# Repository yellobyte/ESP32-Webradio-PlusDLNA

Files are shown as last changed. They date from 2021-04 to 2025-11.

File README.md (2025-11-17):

# ESP32 Webradio++

This ESP32 internet radio implementation is partially based on Ed Smallenburgs (ed@smallenburg.nl) original ESP32 Radio project, version 10.06.2018. His active & very popular web radio project is documented [here](https://github.com/Edzelf/ESP32-radio).  

It all started when my much loved 1991's FM Tuner device **TECHNICS Tuner ST-G570** became obsolete and useless (at least for me). I simply couldn't listen to my favourite FM radio stations anymore after having moved abroad. Since I didn't want to part with the old longtime pal, the decision was made to give it a second life: housing a modern internet radio with lots of additional features.  

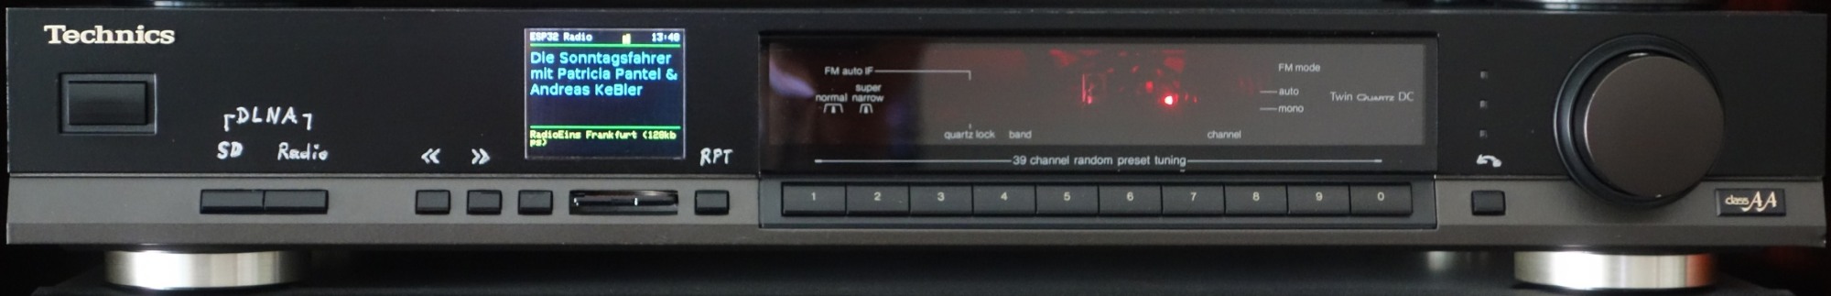
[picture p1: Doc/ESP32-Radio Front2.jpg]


Now, after putting countless hours into the project, the device not only plays **internet radio streams** and audio files from **SD cards** but also **audio content from DLNA media servers** in the same LAN.  

The Arduino library **SoapESP32** has been created especially for the latter feature and enables any ESP32 based device to connect to DLNA media servers in the local network, browse their content and download selected files. It is basically a byproduct of this project and is now listed in the official Arduino library [collection](https://www.arduino.cc/reference/en/libraries/category/communication/).  

## :gift: Feature list:

Starting from Ed Smallenburg's code (Version 10.06.2018) this project has seen a lot of additions and modifications over time. Here a summary:

 * Integration of [SoapESP32](https://github.com/yellobyte/SoapESP32) library for DLNA media server access
 * Digital audio output added (TOSLINK optical) using a WM8805 module from Aliexpress
 * Usage of special VS1053 decoder board (with I2S output and without 3.5mm audio socket)<br />
   -> You find the Eagle schematic & board files [here](https://github.com/yellobyte/ESP32-Webradio-PlusDLNA/tree/main/EagleFiles).
 * VS1053 gets patched with new firmware v2.7 at each reboot<br />
   -> Latest firmware patches for the VLSI VS1053 are available from [here](http://www.vlsi.fi/en/support/software/vs10xxpatches.html).
 * VU meter added to TFT display (needs above mentioned firmware patch)
 * Usage of W5500 Ethernet module instead of ESP32 builtin WiFi
 * Option to use a Debug Server on port 23 for debug output (in this case the cmd server is disabled due to Ethernet socket shortage)
 * Handling of the original front panel buttons & LEDs with the aid of an extender module (connected to ESP32 via I2C)
 * SD card indexing code rewritten in large parts
 * Ability to update ESP32 Radio code via SD card (using OTA functionality during reboot)
 * New rotary encoder fitted to available rotary knob, debouncing done in hardware
 * Track progress bar while playing audio files from SD card or media server
 * Minor modifications to get an unspecified Ali 21-button remote control working
 * MQTT functionality & battery stuff removed completely
 * Handling of more special chars in webradio streams (some radio channels seem to have different utf8 conversion tables)
 * Quicker handling of (very rare) firmware crashes resulting in shorter recovery/reboot time
 * Countless minor changes, adjustments, bugfixing
 * Regular modifications if required for building with new espressif32 framework releases   

If interested, have a look at [Revision history.txt](https://github.com/yellobyte/ESP32-Webradio-PlusDLNA/blob/main/Doc/Revision%20history.txt) in the doc folder. 

## Some technical details:
The original display (rendered useless) has been removed and it's plexiglass cover now hides the infrared sensor VS1838B which receives signals from a remote control. A small 1.8" TFT color display (160x128 pixel, ST7735 driver IC, PCI bus) has been added to the front and is used for interacting with the user and presenting essential info. The necessary cutout in the front has been made with a small and affordable Proxxon mill/drill unit used by many hobbyists. A thin plexiglass is glued into the cutout. The TFT display sits right behind it, mounted on a frame made from PCB material to keep it in place. 

After milling/drilling the front was thoroughly cleaned to get a smooth surface and then the upper flat part of it was painted black twice with a bottle of color spray. It rested 3 days in the sun to dry completely before being reattached to the case. A silver permanent marker was used to label the buttons later on.  

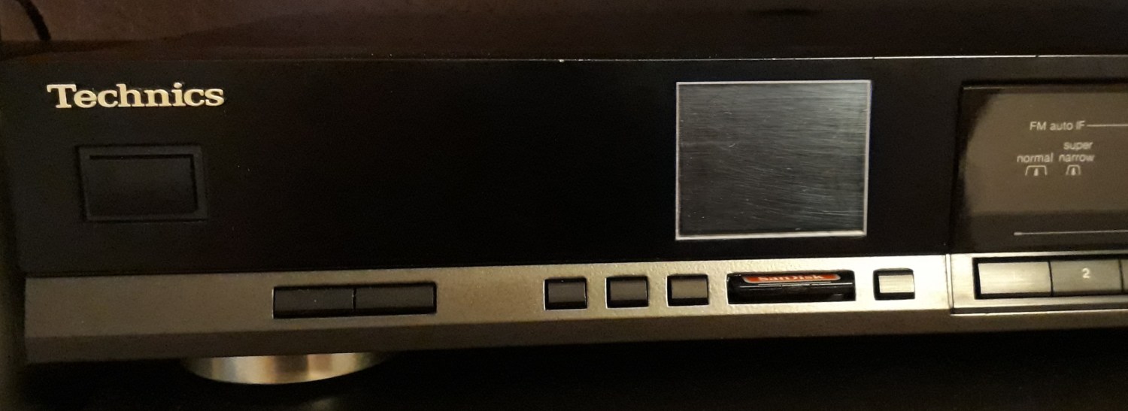
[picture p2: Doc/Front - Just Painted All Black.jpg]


The original encoder attached to the rotary knob has been replaced with a modern one (Stec Rotary Encoder STEC11B03, 1 impulse per 2 clicks, turn + push). The knob is now used to browse through the list of pre-configured web radio stations, the content of SD cards or DLNA media servers storing thousands of audio files. Going up and down the directory levels and finally selecting an audio file for playing is done very fast with the knob in combination with the small 'return' button next to it.  

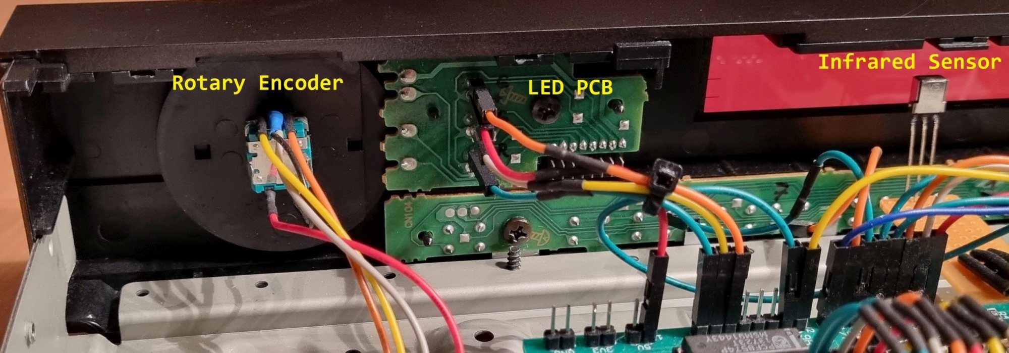
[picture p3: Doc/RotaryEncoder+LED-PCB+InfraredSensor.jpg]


Most of the original front buttons are still available and used for changing modes (Radio, SD card or DLNA), skipping tracks and selecting a repeat mode (None, Track, List or Random). Two adjacent buttons just below the TFT display went into the bin and made room for a SD card module (PCI bus with 4MHz clock speed only for stability reasons).   

A special extender board connects the mainboard with the original front PCB. This board makes it possible to control LEDs and buttons via the original control matrix. The existing 10 channel buttons (1...8,9,0) can continue to serve their original purpose, only this time with web radio stations assigned. The infrared sensor is attached to the extender board as well. 

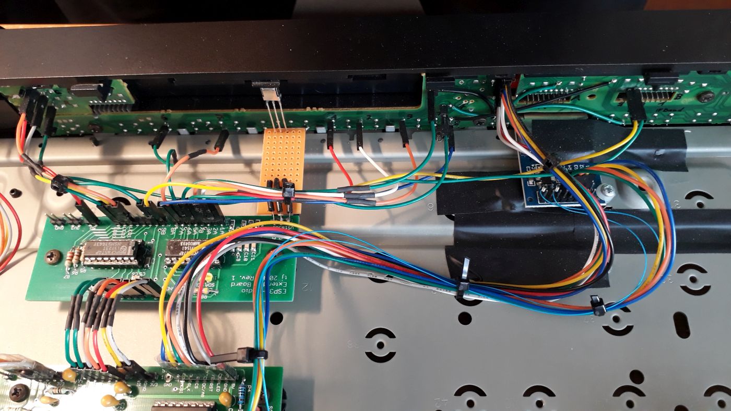
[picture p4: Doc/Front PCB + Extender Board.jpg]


The extender board contains two 'Remote 8-Bit I/O Expander for I2C Bus ICs' PCF8574 and is connected to the mainboard via I2C bus. Its only task is to provide additional IO ports to the ESP32 on the mainboard. Jumper JP1 on the board is open as the interrupt signal INT from both ICs is unused. Every ~60ms the ICs get polled from the ESP32 instead.

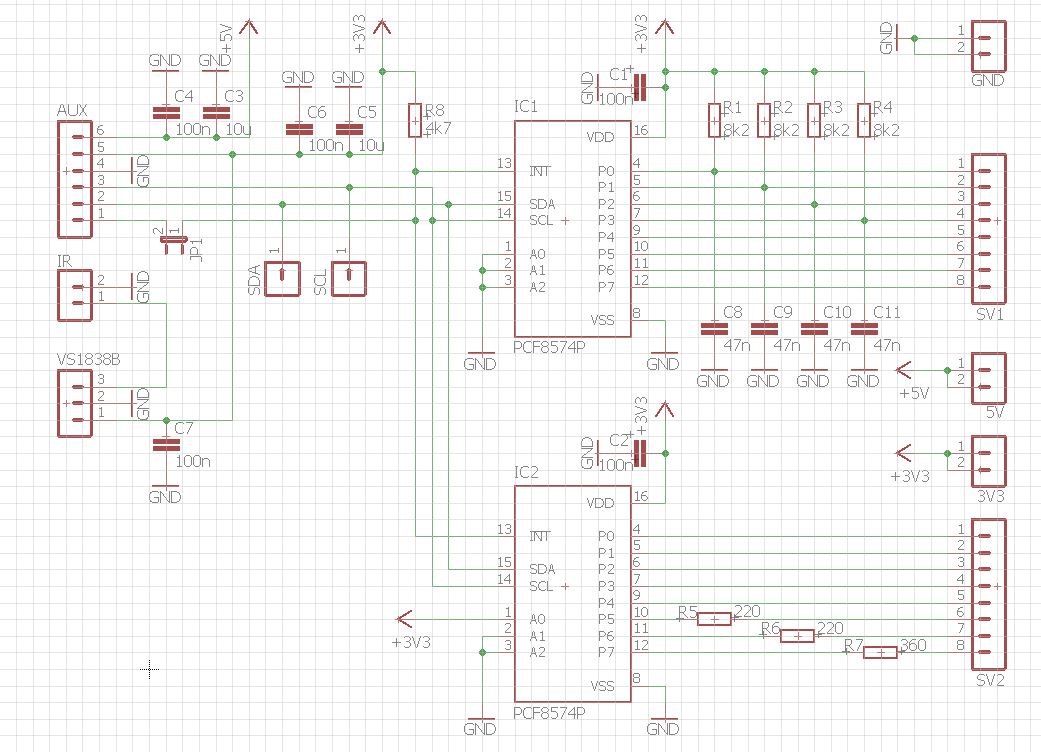
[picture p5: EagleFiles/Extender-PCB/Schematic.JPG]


The original front panel 7x4 control matrix has all buttons connected between 7 rows and 4 columns as shown below. Quite a few single header pins had to be soldered onto the front panel PCB to get electrical access to the matrix. 

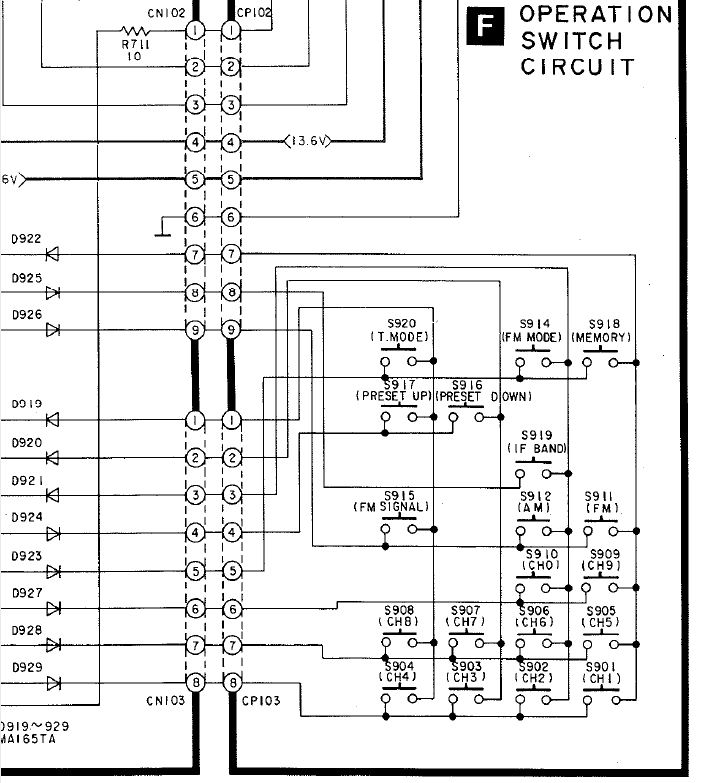
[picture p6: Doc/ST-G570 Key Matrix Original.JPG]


Rows 1...7 of the matrix (from top to bottom) are wired to connectors SV1 and SV2 on the extender board as follows:  
 * Row 1 (CP103/5) --> SV1/5 (PCF8574-1/P4, output)
 * Row 2 (CP103/4) is unused (buttons 'Preset up/down' have been removed)
 * Row 3 (CP102/8) --> SV2/2 (PCF8574-2/P1, output)
 * Row 4 (CP102/9) --> SV2/1 (PCF8574-2/P0, output)
 * Row 5 (CP103/6) --> SV1/6 (PCF8574-1/P5, output)
 * Row 6 (CP103/7) --> SV1/7 (PCF8574-1/P6, output)
 * Row 7 (CP103/8) --> SV1/8 (PCF8574-1/P7, output)

And colums 1...4 (from left to right) are wired to the extender board as follows:  
 * Column 1 (CP103/1) --> SV1/1 (PCF8574-1/P0, input, with 8.2k pull-up resistor to 3V3)
 * Column 2 (CP103/2) --> SV1/2 (PCF8574-1/P1, input, with 8.2k pull-up resistor to 3V3)
 * Column 3 (CP103/3) --> SV1/3 (PCF8574-1/P2, input, with 8.2k pull-up resistor to 3V3)
 * Column 4 (CP102/7) --> SV1/4 (PCF8574-1/P3, input, with 8.2k pull-up resistor to 3V3)

In order to detect pressed buttons the extender board successively pulls the rows LOW and checks it's column input lines for a HIGH to LOW transition because any button pressed will then subsequently pull its corresponding column to LOW as well.

The extender board additionally drives the 3 front panel LEDs via IC PCF8574-2/P5-P7 (connector pins SV2/6...8) by setting the lines to LOW. Those 3 lines plus 3V3 are wired directly to a separate LED PCB next to the rotary encoder.  

As for now, the device consists of several separate modules/PCBs. Three modules (ESP32, TOSLINK optical output, 10/100Mb Ethernet) were bought from various internet shops and the other four modules (power supply, mainboard, VS1053B decoder and front extender) were especially designed for this project with EAGLE PCB Design & Layout tool. The PCBs were ordered unassembled from various PCB prototype manufacturers in CN for little money. I did all the soldering myself, the decoder chip VS1053B in a tiny LQFP-48 package was a challenge though. All relevant EAGLE project files, schematics, board layouts etc. are available [here](https://github.com/yellobyte/ESP32-Webradio-PlusDLNA/tree/main/EagleFiles).  

The analog audio output socket, the power input socket, the common mode choke and the many PCB distance holders were harvested from the original tuner PCBs and reused. Their Eagle-Libraries are located [here](https://github.com/yellobyte/Eagle-Component-Library). The mounting holes on the new PCBs were placed in a way to match the existing mounting holes at the bottom of the case.  

A necessary audio amplifier can be connected via the analog audio output or even the TOSLINK optical output for better sound quality. Well, going digital at the output is probably useless for web radio stations only, as their stream bit rates mostly range between 32...128kbps and very rarely top 192kbps.  

The special VS1053B decoder module (the red one in the middle) provides an I2S output which connects the decoder with the TOSLINK optical output module (the green one on the left). Since all available VS1053B decoder modules on Ali etc. lacked an I2S port I unavoidably had to build my own one. 

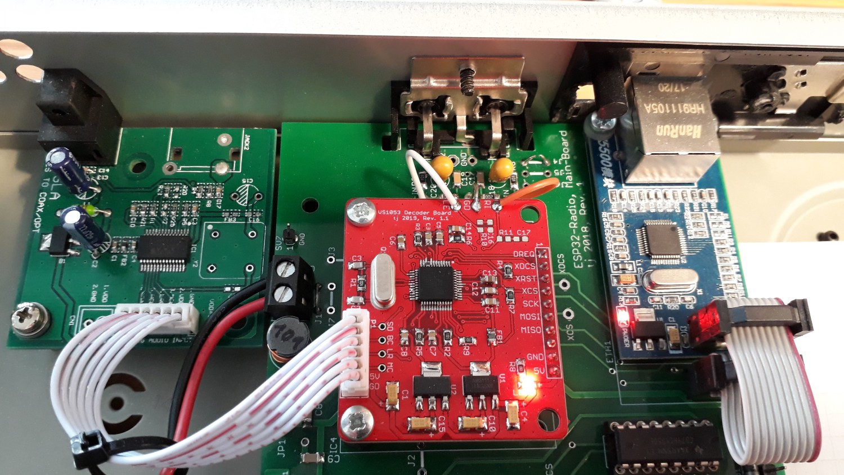
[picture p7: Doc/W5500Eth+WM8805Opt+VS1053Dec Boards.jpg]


If a digital audio output is not needed than any of the available cheap VS1053B decoder modules with 3.5mm jack socket (and without I2S socket) would do.  

The WM8805 I2S to TOSLINK module (China) was the cheapest module version I could get as it lacks the COAX output socket, the crystal oscillator, some Cs, Rs and the power input socket. However, all this is not needed in this project. Important was the ability to configure the WM8805 simply with Rs on the module and the presence of a TOSLINK output socket. 

The WM8805 can be operated in either software or hardware control mode. The mode is determined by sampling the state of the SDIN pin. If SDIN is LOW
during power up or hardware reset then the WM8805 switches into hardware control mode. In this mode most features will assume default values but some can be configured using external pins (SDOUT, SCLK, CSB, GPO0). 

Having the respective Rs soldered as shown below gives the following configuration of the chip: hardware control mode (SDIN=LOW), slave mode (SCLK=LOW), S/PDIF transmitter data source is I2S (CSB=HIGH) and the I2S interface expects 16-bit data (GPO0=LOW, SDOUT=LOW).  

To make the optical output work the decoder chip VS1053B is programmed to feed the WM8805 with 12.288MHz MCLK, 48kHz LRCK (MCLK divided by 256) and 16-bit audio data as configured.

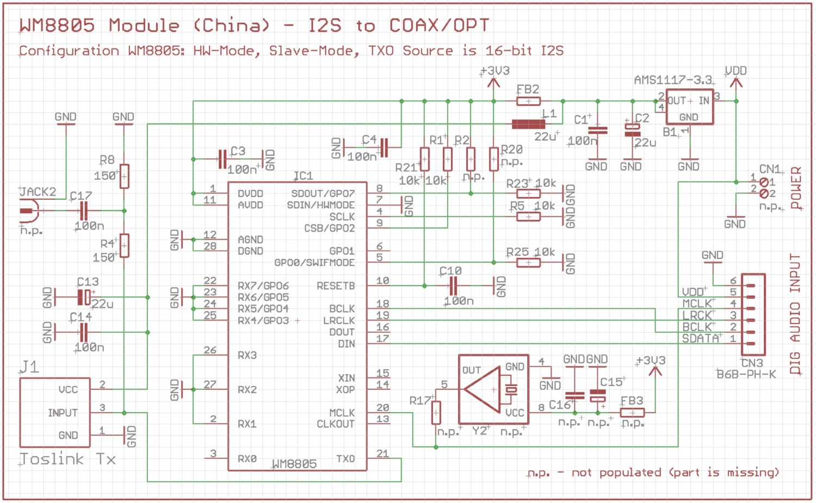
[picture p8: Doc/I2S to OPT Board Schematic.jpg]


The controller board used on the mainboard is an inexpensive ESP32-T dev board equipped with an ESP32-Bit module (4MB Flash, 512kB RAM, no PSRAM, ultra small SMD WLAN antenna, I-PEX WLAN socket). Compared with other popular ESP32 dev boards the ESP32-T is slimmer and therefore even more breadboard compatible. I used it in the first flying test set and since it worked without issues I decided to keep it in the final project.

For my next similar project (this time an old Denon TU-550 tuner case from the early 90's) I will use the [YB-ESP32-S3-ETH dev board](https://github.com/yellobyte/YB-ESP32-S3-ETH) as it combines ESP32 + Ethernet + Wifi + debug port on a single small dev board. Both versions -N4 and -N8R8 will do but the latter provides 8MB PSRAM which allows buffering audio streams if that was needed. This board will allow to make the main board much smaller as well.

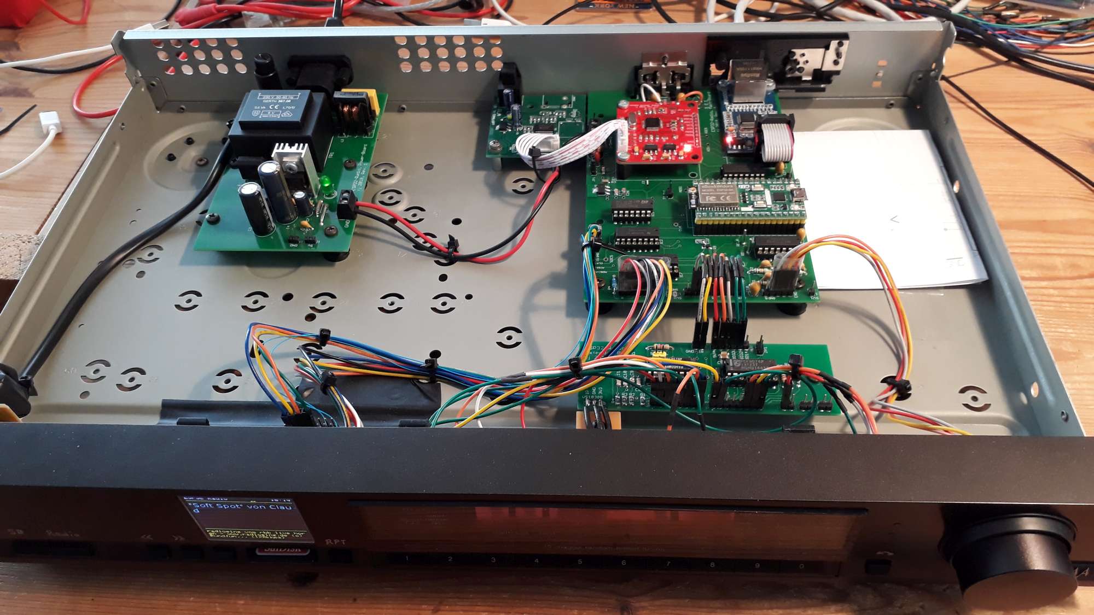
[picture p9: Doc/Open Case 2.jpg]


During the early stages of the project a lot of software updates were required and all were done via USB cable between ESP32-module and PC. However, at some stage the device rejoined the HiFi rack and opening the case now and then for a quick software update became a real pain in the butt. Hence the possibility to perform an ESP32 firmware update simply via SD card was added.  

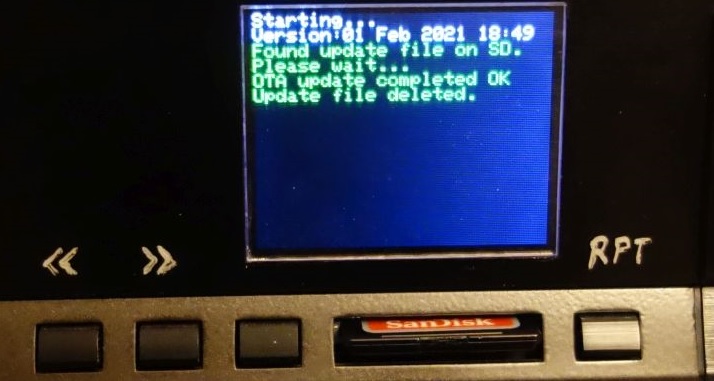
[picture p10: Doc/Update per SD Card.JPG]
  

Plenty of holes were drilled at the back of the case for better thermal management but they later proved unnecessary as the temps inside the case always stayed below 35 degs even with the lid on and all holes covered.  

If Ethernet is not wanted/possible than a small WLAN antenna attached with a short cable to the ESP32 WLAN-socket (I-PEX) would suffice. In that case I recommend to place the antenna directly behind the plexiglass cover for better receiption. Early tests with a WLAN router in 3m distance and fully closed case showed no issues with that arrangement.  

## Hardware troubleshooting:

In the early stages of the project the device was sometimes not able to establish an Ethernet connection after being switched on and it took me quite a while to figure out the problem. As it turned out, the W5500 Ethernet chip needs to be resetted substantially longer after power on than e.g the ESP32 chip.  Hence I modified the mainboard and replaced the original RC combination holding the reset line low with a Microchip MCP130T-315. This is a voltage supervisory IC designed to keep a microcontroller or any other chip in reset for a determined time (typically 350ms) after the system voltage has reached the desired level (here >= 3.15V) and stabilized. With that chip the connection issue vanished for good. 

Another troubling issue were the infrequent system resets after inserting a SD card into the SD card socket while the system was running. I figured it might be the MISO signal from the SD card module being directly attached to the ESP32. After adding driver gates IC2B (HC4050) and IC3D (74HC125) into the path between ESP32 and SD module this problem was gone as well. This solution disconnects the SD modules's MISO signal from the system and therefor prevents any interference from the SD card module when its assigned chip select signal SDCS is inactive (high). 

Since mechanical rotary encoders (independent of their build quality) need to be debounced I decided very early in the project to perform it fully in hardware by using RC circuits (10k/100n) in combination with Schmitt-Trigger ICs (74HC14).  As expected, debouncing issues never surfaced and no line of code had to be wasted on this topic.  

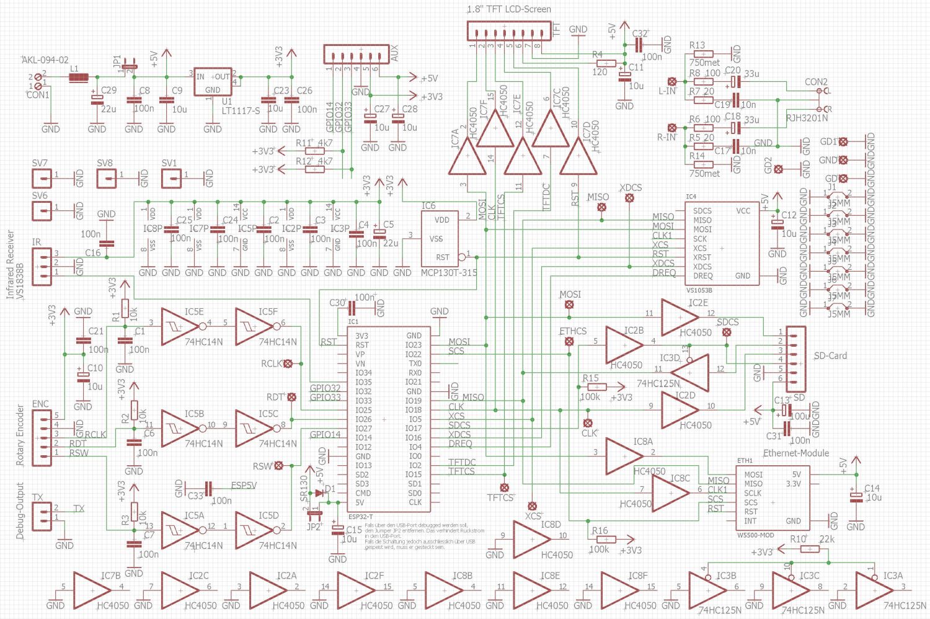
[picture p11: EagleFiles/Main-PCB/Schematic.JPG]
  

As visible in the main board schematic above, the inputs of all unused 74HC gates are kept grounded and not floating in order to avoid possible gate oscillation as their inputs are all high impedance (in contrast to e.g. old 7400's). Furthermore I added plenty of capacitors near the ICs and close to each socket, connector etc. in order to keep the power supply rail as clean as possible.

## :zap: Software application notes:

All coding was done with **VSCode/PlatformIO-IDE**. To install needed libraries (Ethernet, SoapESP32, etc.) click the **PlatformIO sidebar icon**, open the **libraries** view and search for libs. Once found, select the newest release and click on **Add to Project**.

Always make sure you have one of the latest versions of **Arduino espressif32 framework** installed. Older versions might produce build errors. Building the project was successfully done with latest espressif32 frameworks V4.2.0, V5.0.0 and V6.0.0. Have a look at file [platformio.ini](https://github.com/yellobyte/ESP32-Webradio-PlusDLNA/blob/main/Software/platformio.ini) for required settings.

**Important:**  
Building with the official Arduino Ethernet library **and** with build options `ENABLE_CMDSERVER` or `PORT23_ACTIVE` will produce a build error like this:  
```
src\main.cpp:394:19: error: cannot declare variable 'cmdserver' to be of abstract type 'EthernetServer'
 EthernetServer    cmdserver(80);                         // Instance of embedded webserver, port 80
In file included from C:\users\tj\.platformio\packages\framework-arduinoespressif32\cores\esp32/Arduino.h:152:0,
                 from src\main.cpp:108:
C:\users\tj\.platformio\packages\framework-arduinoespressif32\cores\esp32/Server.h:28:18: note:         virtual void Server::begin(uint16_t)
     virtual void begin(uint16_t port=0) =0;
```
In this case file *Ethernet.h* in the Ethernet lib needs to be modified. Just change line  
```
class EthernetServer : public Server {
```
to
```
class EthernetServer : public Print {
```

## :tada: Implementation of SoapESP32 library for DLNA server access

The lib makes retrieving audio files from a DLNA media server a breeze: Function *browseServer()* is used to scan the server content and return a list of tracks (audio files). The device then selects an item from the list and sends a read request to the media server using *readStart()*. If granted, it will repeatedly *read()* a chunk of data into the queue which feeds the audio codec VS1053B until end of file. Finally the data connection to the server is closed with *readStop()* and the next item from the list is requested, provided the 'repeat file/folder' mode is active.  

The following sample picture sequence shows the actual implementation into this webradio project:

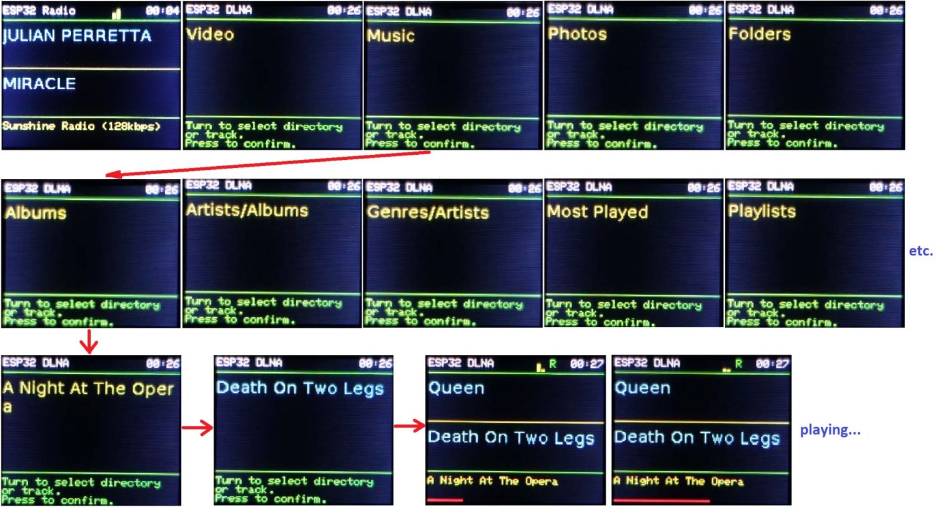
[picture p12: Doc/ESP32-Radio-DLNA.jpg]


Alternatively have a look at the short clip _ESP32-Radio-DLNA.mp4_ in folder **Doc** to see the final implementation in action. To watch now, click [Here](https://github.com/yellobyte/ESP32-Webradio-PlusDLNA/blob/main/Doc/ESP32-Radio-DLNA.mp4).

## :hammer_and_wrench: Still to be done:

 * Enable the Webinterface to browse DLNA media servers and select audio files for playing.

## :relaxed: Postscript:

Maybe this project can inspire one or two owners of old HiFi equipment to give their devices a second chance instead of tossing them into the scrap metal container. I spent a lot of time and efforts doing this project and wouldn't want to miss a second of it for I had plenty of fun and learned many things as well.  

If you have questions, miss some information or have suggestions, feel free to create an issue or contact me. However, my response time might be slow at times.

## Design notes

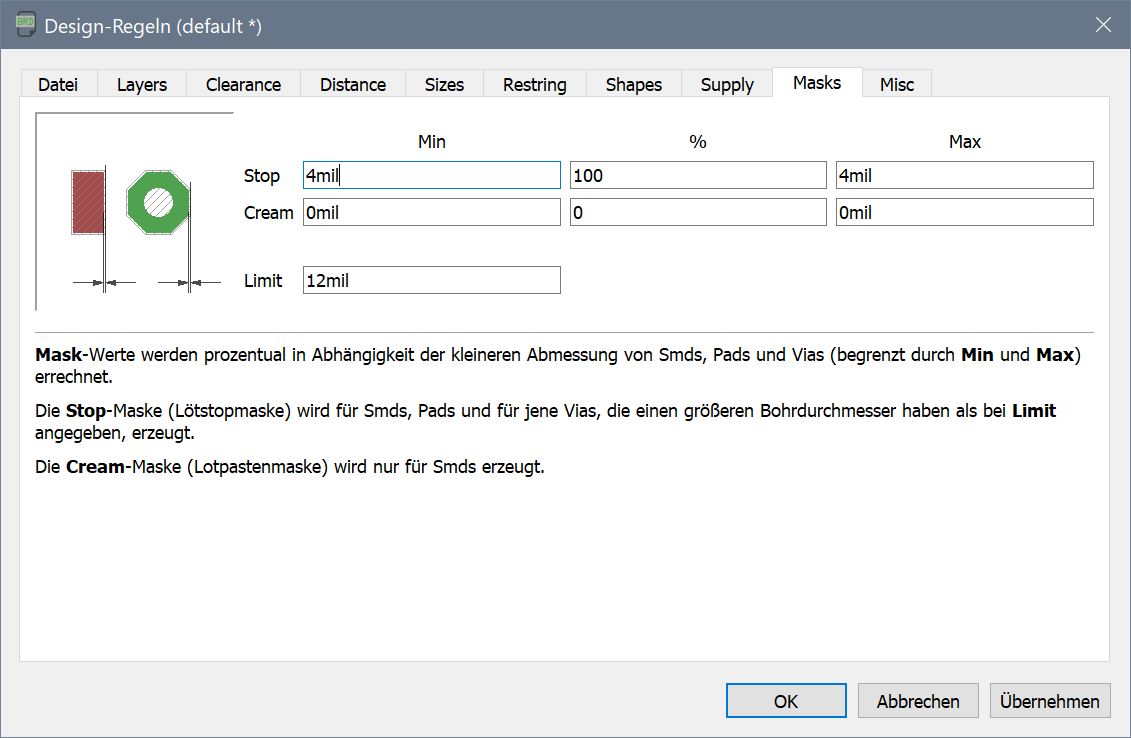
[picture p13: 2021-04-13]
EagleFiles/VS1053-PCB/Design-Masks.JPG

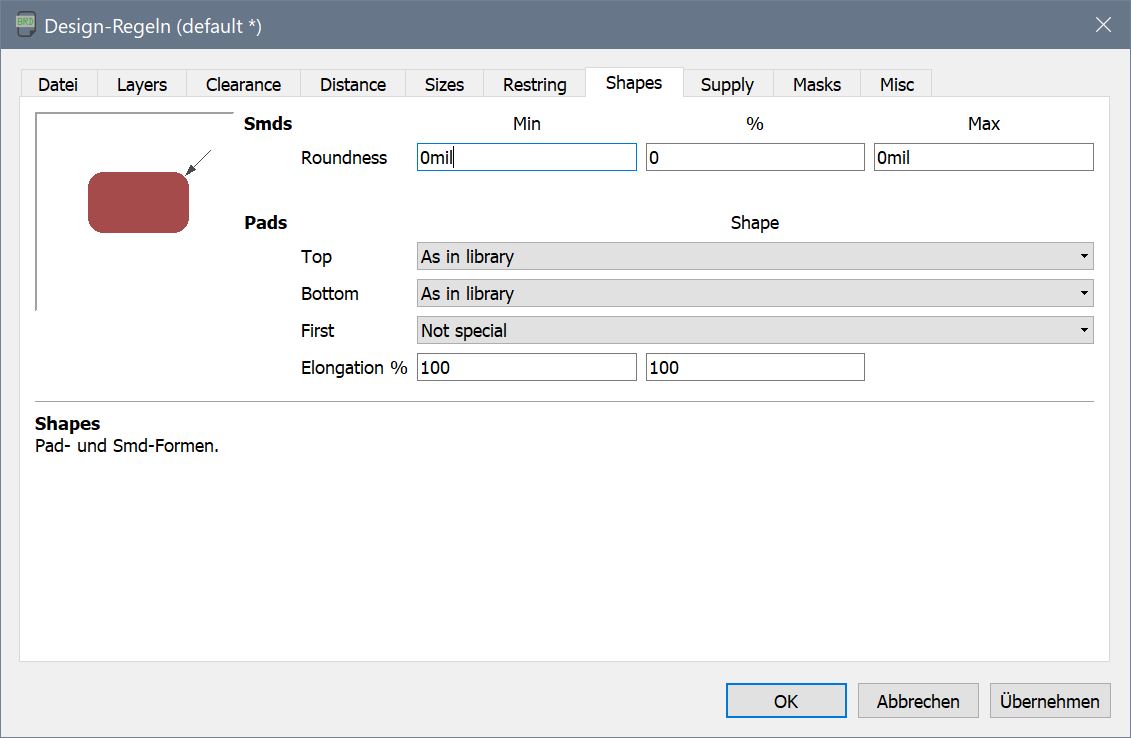
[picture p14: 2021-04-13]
EagleFiles/VS1053-PCB/Design-Shapes.JPG

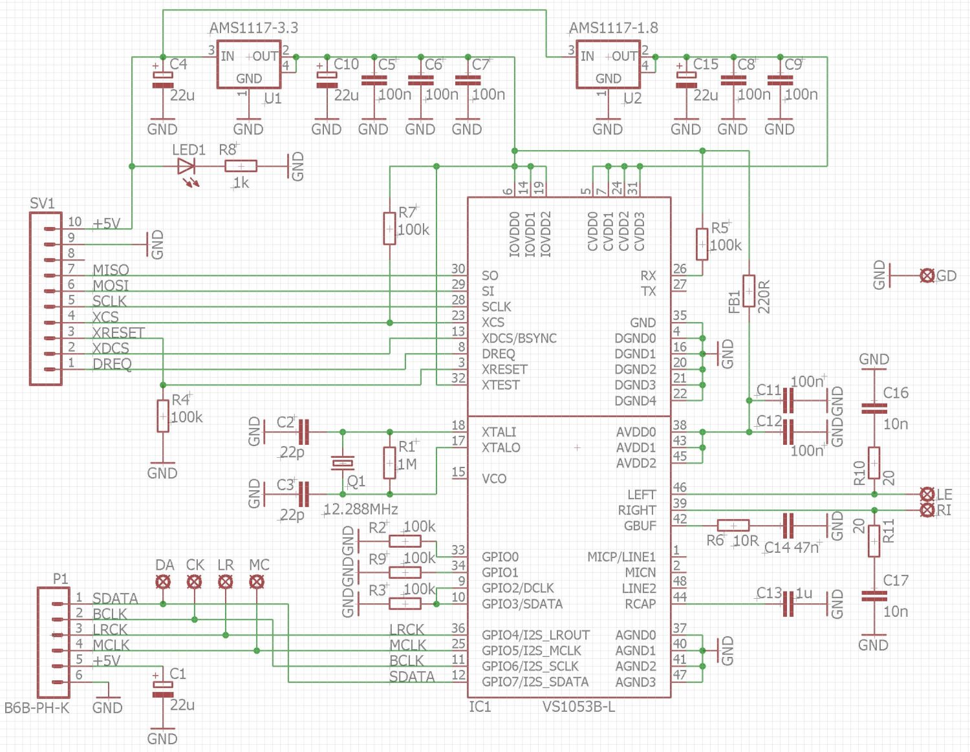
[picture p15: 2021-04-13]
EagleFiles/VS1053-PCB/Schematic.JPG

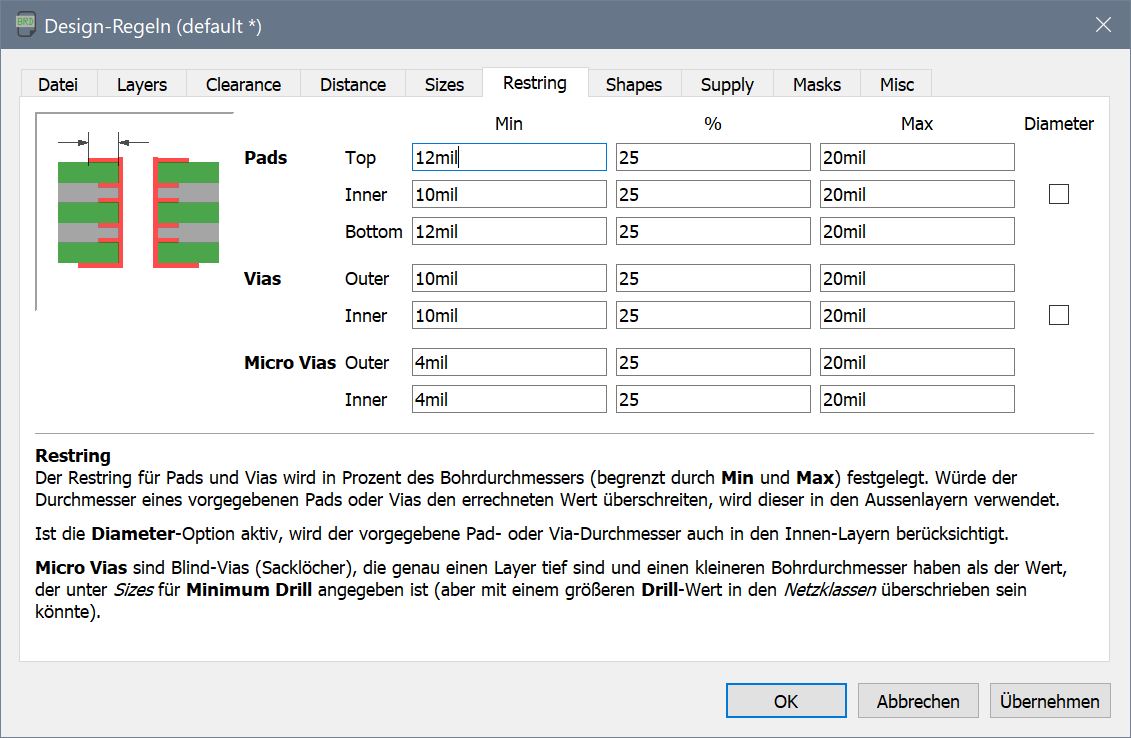
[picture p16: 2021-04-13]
EagleFiles/Main-PCB/Design-Restring.JPG

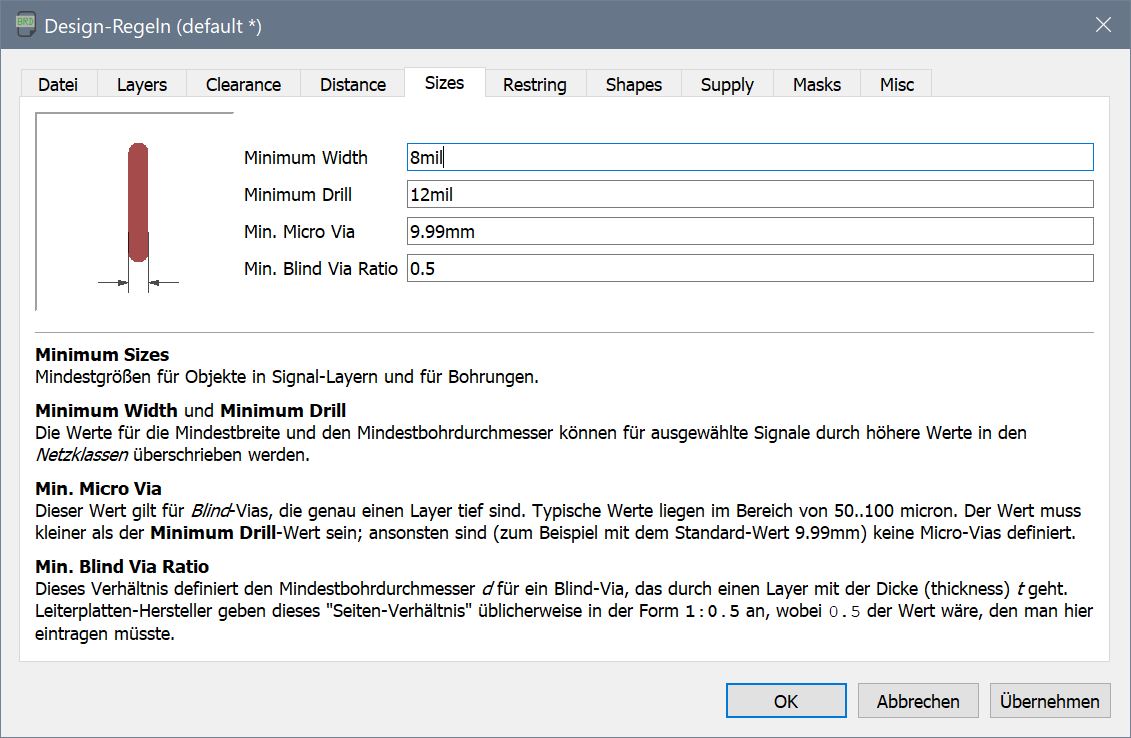
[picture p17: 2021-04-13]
EagleFiles/VS1053-PCB/Design-Sizes.JPG

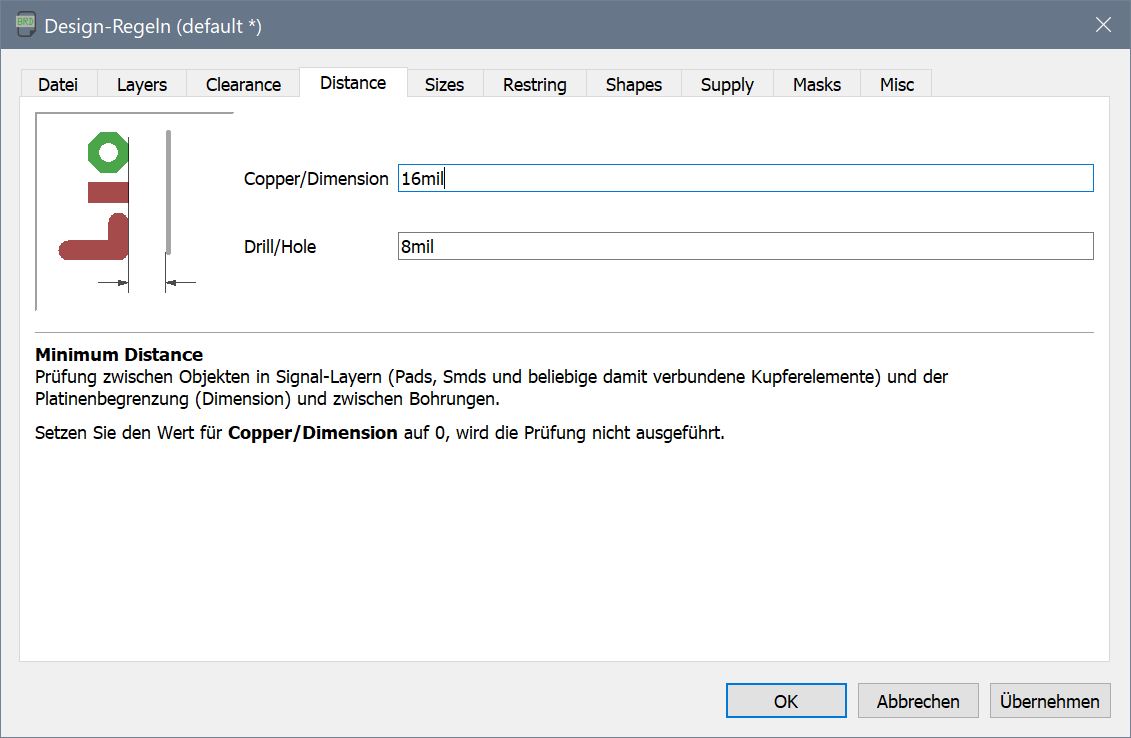
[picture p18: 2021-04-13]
EagleFiles/Main-PCB/Design-Distance.JPG

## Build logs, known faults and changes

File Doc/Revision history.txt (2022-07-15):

26-04-2017, ES: First set-up, derived from ESP8266 version.
08-05-2017, ES: Handling of preferences.
22-05-2017, ES: Save preset, volume and tone settings.
23-05-2017, ES: No more calls of non-iram functions on interrupts.
24-05-2017, ES: Support for featherboard.
26-05-2017, ES: Correction playing from .m3u playlist. Allow single hidden SSID.
30-05-2017, ES: Add SD card support (FAT format), volume indicator.
26-06-2017, ES: Correction: start in AP-mode if no WiFi networks configured.
28-06-2017, ES: Added IR interface.
30-06-2017, ES: Improved functions for SD card play.
03-07-2017, ES: Webinterface control page shows current settings.
08-07-2017, ES: More space for streamtitle on TFT.
18-07-2017, ES: Time Of Day on TFT.
19-07-2017, ES: Minor corrections.
26-07-2017, ES: Flexible pin assignment. Add rotary encoder switch.
27-07-2017, ES: Removed tinyXML library.
18-08-2017, Es: Minor corrections
28-08-2017, ES: Preferences for pins used for SPI bus,
                Corrected bug in handling programmable pins,
                Introduced touch pins.
30-08-2017, ES: Added MDNS responder.
11-11-2017, ES: Increased ringbuffer.  Measure bit rate.
13-11-2017, ES: Forward declarations.
16-11-2017, ES: Replaced ringbuffer by FreeRTOS queue, play function on second CPU,
                Included improved rotary switch routines supplied by fenyvesi,
                Better IR sensitivity.
30-11-2017, ES: Hide passwords in config page.
01-12-2017, ES: Better handling of playlist.
07-12-2017, ES: Faster handling of config screen.
08-12-2017, ES: Added pin_shutdown.
13-12-2017, ES: Correction clear LCD.
15-12-2017, ES: Correction defaultprefs.h.
18-12-2017, ES: Stop playing during config.
02-01-2018, ES: Stop/resume is same command.
22-01-2018, ES: Read ADC (GPIO36) and display as a battery capacity percentage.
13-02-2018, ES: Stop timer during NVS write.
15-02-2018, ES: Correction writing wifi credentials in NVS.
03-03-2018, ES: Correction bug IR pinnumber.
05-03-2018, ES: Improved rotary encoder interface.
10-03-2018, ES: Minor corrections.
13-04-2018, ES: Guard against empty string send to TFT, thanks to Andreas Spiess.
16-04-2018, ES: ID3 tags handling while playing from SD.
25-04-2018, ES: Choice of several display boards.
30-04-2018, ES: Bugfix: crash when no IR is configured, no display without VS1063.
08-05-2018, ES: 1602 LCD display support (limited).
11-05-2018, ES: Bugfix: incidental crash in isr_enc_turn().
30-05-2018, ES: Bugfix: Assigned DRAM to global variables used in timer ISR.
31-05-2018, ES: Bugfix: Crashed if I2C is used, but pins not defined.
01-06-2018, ES: Run playTask on CPU 0.
04-06-2018, ES: Made handling of playlistdata more tolerant (NDR).
09-06-2018, ES: Typo in defaultprefs.h
10-06-2018, ES: Rotary encoder, interrupts on all 3 signals.
21-06-2018, TJ: Bugfix in ID3-Tag recognition, new: utf16ascii()
22-06-2018, TJ: reconnect to same station as first try if station is lost
25-06-2018, TJ: unused MQTT & battery parts removed
27-06-2018, TJ: Bugfix in getSDfilename(), repeat-Mode added
01-07-2018, TJ: Showing directory names on tracklist in web interface
02-07-2018, TJ: Fast Forward for mp3 files added + misc bug fixes + changes for encoder handling
07-07-2018, TJ: Bugfixing showStreamTitle(), Changes for TFT Output with different Fonts etc.
12-07-2018, TJ: Changes in TFT Layout, progress bar, more bug fixing
15-07-2018, TJ: Ethernet added (per #define changeable between WiFi or Ethernet)
16-07-2018, TJ: DHCP or static IP addresses configurable via preferences. If rotary button is pressed
                while rebooting than DHCP will be tried first
17-07-2018, TJ: NTP server access when Ethernet/LAN is used, getLocalTimeEth()
22-07-2018, TJ: Completely new design for file listing & indexing
06-08-2018, TJ: Bugfixing in various functions, changes in mp3loop
25-08-2018, TJ: Completely different Encoder handling (spikes are now suppressed by hardware)
27-08-2018, TJ: Connecting to Port Extender ICs PCF8574 via I2C
28-08-2018, TJ: Handling of original TECHNICS ST-G570 front panel buttons & LEDs
06-09-2018, TJ: ESP32-I2C system doesn't work stable. We generate our own I2C code. Quick & dirty.
07-09-2018, TJ: Changing front panel behaviour heavily
26-09-2018, TJ: Bug fixing, changings in defaultprefs.h
08-10-2018, TJ: Changes for displaying Radio stations
16-10-2018, TJ: I2C software changed (we use low level I2C functions now, i2c_xxx [provided by espressif])
30-11-2018, TJ: In case no station name gets send we use preset name (if it exists)
01-12-2018, TJ: Show selected station names instantaneously when skip/preset buttons pressed
02-12-2018, TJ: getTime() & mp3loop() optimized, defaultprefs.h modified
03-12-2018, TJ: playing iRadio stations optimized, bugfixing
29-01-2019, TJ: MP3 progress bar with finer granularity
09-02-2019, TJ: Debug Output on Port 23 added (if PORT23_ACTIVE defined)
11-02-2019, TJ: We use standard Arduino Ethernet Library V2.0.0 instead of Wiznet Library
06-03-2019, TJ: SD_MAXDEPTH increased, Error message improved for swapped SD cards, 
                System Volume Directories suppressed in SD track list
15-05-2019, TJ: Re-Init W5500 ethernet card if connection to server is lost
16-05-2019, TJ: Removed mp3client.flush() from stopMp3client(): it hangs quite often !
08-09-2019, TJ: Show more chars in bottom segment when in radio mode (incl. conversion of spec. chars)
12-09-2019, TJ: quickSdCheck() for better handling of removed/re-inserted SD-cards
20-09-2019, TJ: File selection process from SD card slightly changed
08-10-2019, TJ: SD-Card is not scanned after switching on, only if user presses SD button.
                This speeds up the boot process.
11-10-2019, TJ: I2S Interface turned on (for new VS1053B decoder board & optical digital output),
                VS1053B patch V2.7 is loaded into VS1053B chip at every system boot and Bits 8 & 0 in
                register SCI_STATUS are set, this activates a higher reference voltage
19-10-2019, TJ: The VS1053 patch introduces a VU-Meter function. We use it in the new task "vumeterTask". 
18-04-2020, TJ: Switching from SD- to Station-Mode selects the actual station preset and not the first station
19-04-2020, TJ: Introduced Update via SD-Card (File "firmware.bin" must be in root directory)
28-11-2020, TJ: Update for VU-Meter, adjust VU meter for changing levels: radio/sdcard produce different output levels & dynamic
01-12-2020, TJ: utf8ascii modified
02-01-2020, TJ: integration of SoapESP32 for playing files from DLNA media server
09-04-2022, TJ: mp3play_html.h modified (ensure refresh of mp3 list)
10-05-2022, TJ: Faster recovery after loss of station (timer10sec() -> timer5sec())
14-07-2022, TJ: Required modifications for espressif32 frameworks >= V4.2.0
15-07-2020, TJ: utf8ascii(), displayinfo() and limitString() improved

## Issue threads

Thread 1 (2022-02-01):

Build errors

artiezz, 2022-02-01:
Using VS/PlatformIO.
First attempt: Ethernet.h: No such file or directory. Followed suggested link and added lib_deps = arduino-libraries/Ethernet@^2.0.0 to platformio.ini.
Second attempt: SoapESP32.h: No such file or directory. I gave up.
Have you built this code from a clean load?

yellobyte, 2022-02-02:
In VSCode/PlatformIO click the platformio sidebar icon, open the libraries view and search for Ethernet & SoapESP32. Once found, always select the newest release and click on **Add to Project**.
Try this in platformio.ini:
```
lib_deps = Wire, Adafruit BusIO, SoapESP32, Ethernet
lib_ldf_mode = chain+
```

Build log should look similar like this:
```c
Scanning dependencies...
Dependency Graph
|-- <Wire> 1.0.1
|-- <Adafruit BusIO> 1.10.3
|   |-- <Wire> 1.0.1
|   |-- <SPI> 1.0
|-- <SoapESP32> 1.1.1
|   |-- <Ethernet> 2.0.0
|   |   |-- <SPI> 1.0
|-- <FS> 1.0
|-- <SD(esp32)> 1.0.5
|   |-- <FS> 1.0
|   |-- <SPI> 1.0
|-- <SPI> 1.0
|-- <Update> 1.0
|-- <WiFi> 1.0
|-- <Ethernet> 2.0.0
|   |-- <SPI> 1.0
|-- <Adafruit ST7735 and ST7789 Library> 1.8.2
|   |-- <Adafruit GFX Library> 1.10.13
|   |   |-- <SPI> 1.0
|   |   |-- <Adafruit BusIO> 1.10.3
|   |   |   |-- <Wire> 1.0.1
|   |   |   |-- <SPI> 1.0
|   |   |-- <Wire> 1.0.1
|   |-- <SPI> 1.0
|-- <Adafruit GFX Library> 1.10.13
|   |-- <SPI> 1.0
|   |-- <Adafruit BusIO> 1.10.3
|   |   |-- <Wire> 1.0.1
|   |   |-- <SPI> 1.0
|   |-- <Wire> 1.0.1
Building in release mode
Compiling .pio\build\esp32dev\libc42\Adafruit BusIO\Adafruit_BusIO_Register.cpp.o
........
Archiving .pio\build\esp32dev\lib2c1\libAdafruit ST7735 and ST7789 Library.a
Archiving .pio\build\esp32dev\lib278\libAdafruit GFX Library.a
Archiving .pio\build\esp32dev\libc42\libAdafruit BusIO.a
Linking .pio\build\esp32dev\firmware.elf
Retrieving maximum program size .pio\build\esp32dev\firmware.elf
Checking size .pio\build\esp32dev\firmware.elf
Advanced Memory Usage is available via "PlatformIO Home > Project Inspect"
RAM:   [==        ]  17.9% (used 58764 bytes from 327680 bytes)
Flash: [=====     ]  51.7% (used 1016326 bytes from 1966080 bytes)
```
Show me your build log in case you need further help. Tx Th

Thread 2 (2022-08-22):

VS1053 initialisation error

DSangyy, 2022-08-22:
Awsome project you have, i am using it for my mini music client.
I've stumbled upon a problem, ENABLE_DIGITAL_INPUTS must be enabled for VS1053 to work, else it will raise "VS1053 not properly installed". I use pin 27, 14, 26 for cs, dcs, dreq. Guess the problem is pin 26 could not be read properly.

yellobyte, 2022-08-22:
Hi there, thanks for your reply. I appreciate that.
Having a look at the code I see in function readIOprefs() the value for dreq_pin is assigned a default value (in my case: 4) unless you specify otherwise in the config file via Webbrowser.
Then in setup() the VS1053 object is created and initialized with above chosen DREQ pin number:
...
  vs1053player = new VS1053(ini_block.vs_cs_pin,        // Make instance of player
                            ini_block.vs_dcs_pin,
                            **ini_block.vs_dreq_pin,**      <------------- DREQ pin number
                            ini_block.vs_shutdown_pin);
...
A few lines further down is a function call to the VS1053 initialization routine:
...
  **vs1053player->begin();**                               // initialize VS1053 player
...
In this initialization routine the actual ESP32 port (DREQ should be connected to) gets initialized:
...
void VS1053::begin()
{
  **pinMode(dreq_pin, INPUT);**                            // DREQ is an input         <------------- DREQ pin initialized
  pinMode(cs_pin, OUTPUT);                             // the SCI and SDI signals
...
So without ENABLE_DIGITAL_INPUTS being defined the ESP32 DREQ port gets initialized properly in any case. Furthermore after an ESP32 reset all ports are set by default to mode INPUT anyway.
From my point of view defining ENABLE_DIGITAL_INPUTS is not necessary for the VS1053 to work. My project runs ok this way.

You can try modifying above line to  "pinMode(dreq_pin, **INPUT_PULLUP**);" and see if it changes anything. That might suppress the error in case the VS1053 DREQ line is not properly connected to the ESP32 and you don't have a **pullup resistor** on that pin. However, without that connection it won't work later on.
I hope I have understood your problem accurately, otherwise come back to me.
Regards Thomas

yellobyte, 2022-08-24:
An oscilloscope helped me a lot finding errors, wouldn't want to live without one. Let me know how it goes. Good luck.
BTW: If you like this project, please give it a star. Thanks. :-)

Closed 2023-03-18.

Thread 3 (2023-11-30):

How to make simple DLNA audio player?

skylai82, 2023-11-30:
Is this posible using ESp32-s2 to make it DLNA audio player?

yellobyte, 2023-12-02:
The project builds without errors for ESP32/ESP32-S2/ESP32-S3.

skylai82, 2023-12-02:
> The project builds without errors for ESP32/ESP32-S2/ESP32-S3.

Can you share a simple DLNA code?  ：） I want stream my phone Music player to DLNA  ESP32 speaker.

yellobyte, 2023-12-02:
Sorry, I don't get what you want exactly....

skylai82, 2023-12-02:
> Sorry, I don't get what you want exactly....
Make my ESP32-S2 + MAX98357A like product below.
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

skylai82, 2023-12-02:
> You want to receive audio from a dlna server with ESP32, send it to a MAX98357A and play it via loudspeaker ?

Yes, it this possible? :)

yellobyte, 2023-12-02:
yes

yellobyte, 2023-12-04:
It is online: https://github.com/yellobyte/ESP32-Webradio-PlusDLNA/tree/main/Software/src  Feel free to take it as a starting point.

skylai82, 2023-12-04:
> It is online: https://github.com/yellobyte/ESP32-Webradio-PlusDLNA/tree/main/Software/src Feel free to take it as a starting point.

Thanks！ I will try to simplify code to my Internet Radio.
I've seen it before, but it's quite complicated for a beginner like me. ：）
Good Night.

yellobyte, 2023-12-04:
Have fun !

Closed 2023-12-29.

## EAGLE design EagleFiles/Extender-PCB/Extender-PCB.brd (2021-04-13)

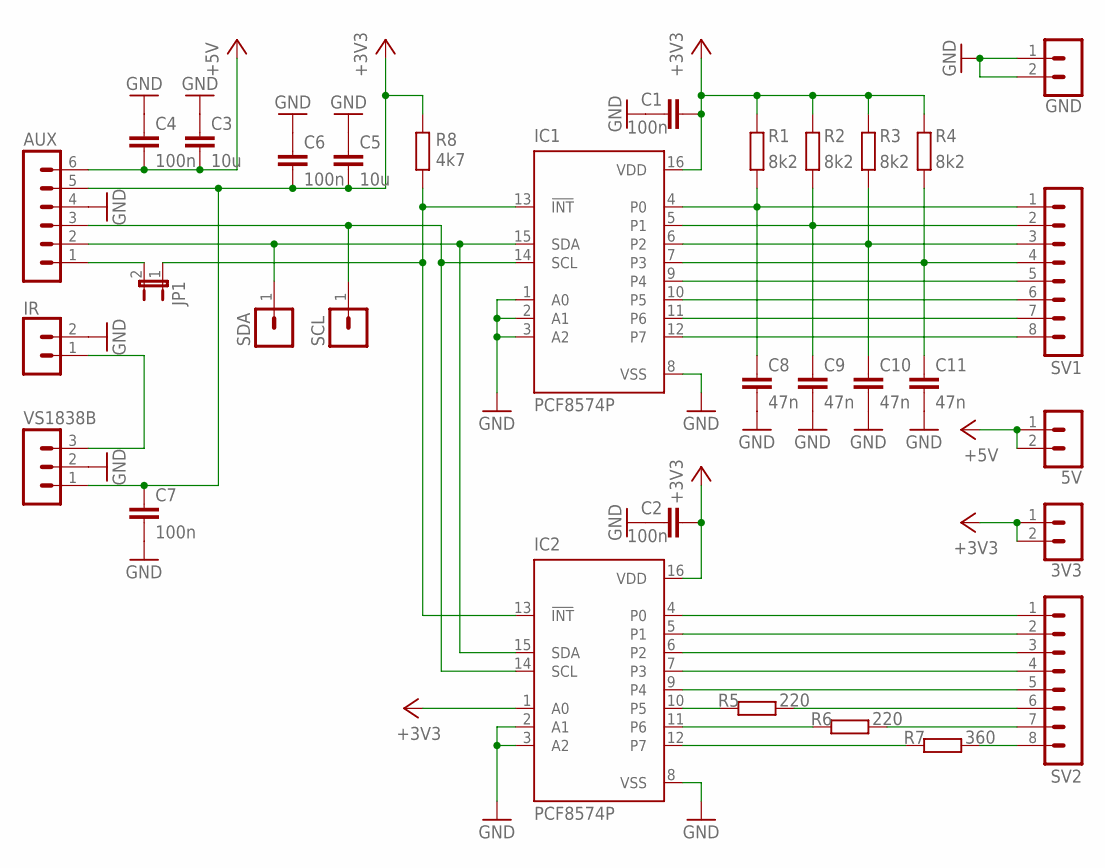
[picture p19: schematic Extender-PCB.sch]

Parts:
3V3, 5V: MA02-1
AUX: MA06-1
C1, C2, C4, C6, C7: 100n; C1206
C3, C5: 10u; C1206
C8, C9, C10, C11: 47n; C1206
GND: MA02-1
IC1, IC2: PCF8574P; DIL16
IR: MA02-1
JP1: JP1E; JP1
R1, R2, R3, R4: 8k2; R1206
R5, R6: 220; 0207/10
R7: 360; 0207/10
R8: 4k7; 0207/10
SCL: MA01-1
SDA: MA01-1
SV1, SV2: MA08-1
VS1838B: MA03-1

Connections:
+3V3: 3V3.1, 3V3.2, AUX.5, C1.2, C2.2, C5.2, C6.2, C7.1, IC1.16 (VDD), IC2.1 (A0), IC2.16 (VDD), R1.2, R2.2, R3.2, R4.2, R8.2, VS1838B.1
+5V: 5V.1, 5V.2, AUX.6, C3.2, C4.2
GND: AUX.4, C1.1, C2.1, C3.1, C4.1, C5.1, C6.1, C7.2, C8.2, C9.2, C10.2, C11.2, GND.1, GND.2, IC1.1 (A0), IC1.2 (A1), IC1.3 (A2), IC1.8 (VSS), IC2.2 (A1), IC2.3 (A2), IC2.8 (VSS), IR.2, VS1838B.2
LED1: R5.2, SV2.6
LED2: R6.2, SV2.7
LED3: R7.2, SV2.8
unnamed: AUX.1, JP1.2
unnamed: IC1.13 (!INT), IC2.13 (!INT), JP1.1, R8.1
unnamed: IR.1, VS1838B.3
P0-1: C8.1, IC1.4 (P0), R1.1, SV1.1
P0-2: IC2.4 (P0), SV2.1
P1-1: C9.1, IC1.5 (P1), R2.1, SV1.2
P1-2: IC2.5 (P1), SV2.2
P2-1: C10.1, IC1.6 (P2), R3.1, SV1.3
P2-2: IC2.6 (P2), SV2.3
P3-1: C11.1, IC1.7 (P3), R4.1, SV1.4
P3-2: IC2.7 (P3), SV2.4
P4-1: IC1.9 (P4), SV1.5
P4-2: IC2.9 (P4), SV2.5
P5-1: IC1.10 (P5), SV1.6
P5-2: IC2.10 (P5), R5.1
P6-1: IC1.11 (P6), SV1.7
P6-2: IC2.11 (P6), R6.1
P7-1: IC1.12 (P7), SV1.8
P7-2: IC2.12 (P7), R7.1
SCL: AUX.3, IC1.14 (SCL), IC2.14 (SCL), SCL.1
SDA: AUX.2, IC1.15 (SDA), IC2.15 (SDA), SDA.1

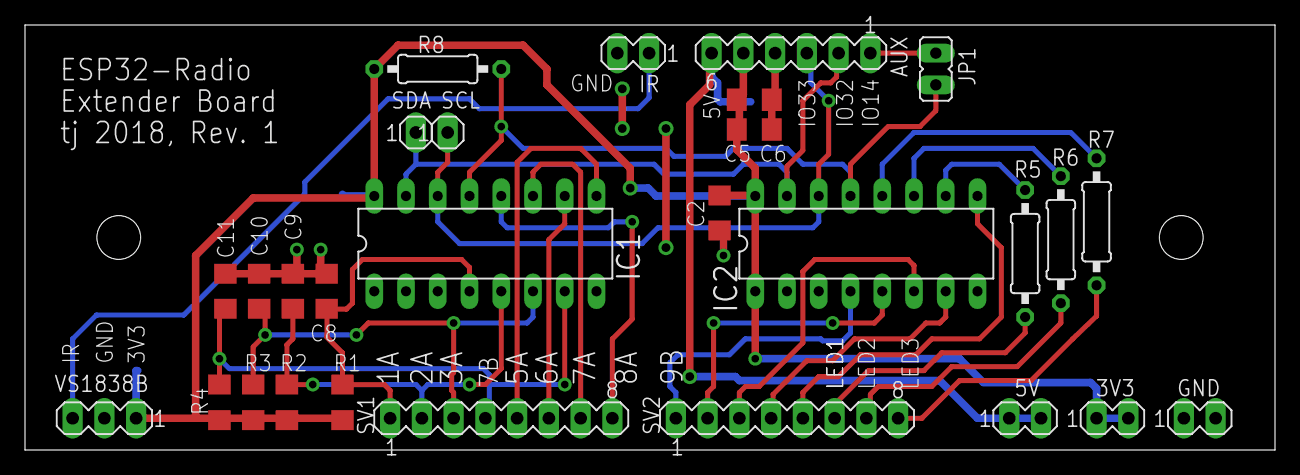
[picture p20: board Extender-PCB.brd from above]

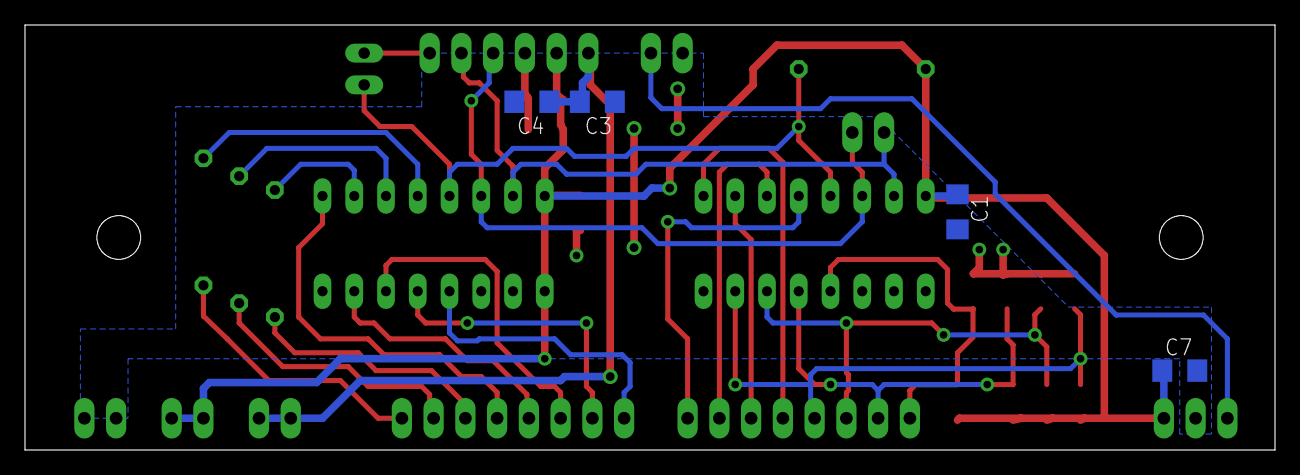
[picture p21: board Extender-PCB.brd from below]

Board: 2 copper layers, 100.0 x 34.0 mm, 32 parts (4 on the bottom side), 27 nets.

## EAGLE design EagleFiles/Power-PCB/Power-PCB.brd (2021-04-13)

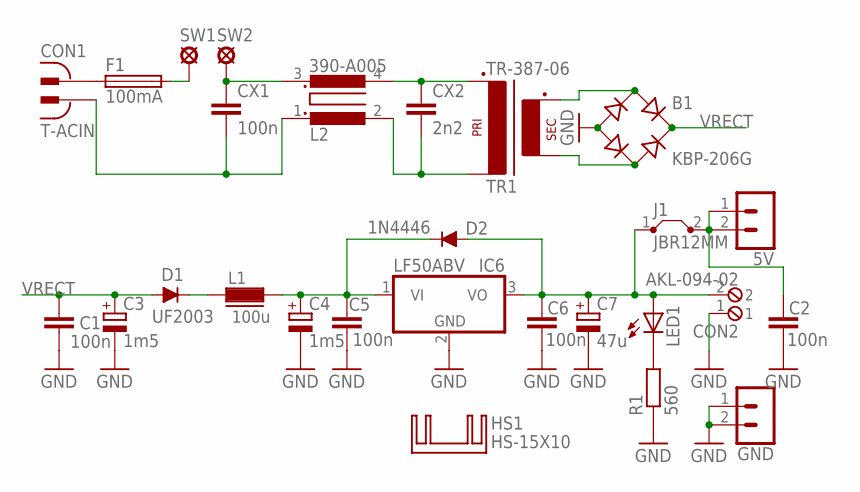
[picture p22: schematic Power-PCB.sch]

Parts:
5V: MA02-1
B1: KBP-206G; 2KBP
C1, C2, C5, C6: 100n; C050-024X044
C3, C4: 1m5; E5-10,5
C7: 47u; E2,5-6
CON1: T-ACIN; TECHNICS-ACIN1
CON2: AKL-094-02
CX1: 100n; XC15B6
CX2: 2n2; C075-032X103
D1: UF2003; DO41-10A
D2: 1N4446; DO35-10
F1: 100mA; KS9V
GND: MA02-1
HS1: HS-15X10; HEATSINK-TO220-15X10X21
IC6: LF50ABV; TO220V
J1: JBR12MM; 12-THICK-WIRE
L1: 100u; 07HCP
L2: 390-A005
LED1: LED5MM
R1: 560; 0207/10
SW1, SW2: SE13
TR1: TR-387-06; TRAFO-GERTH-387-06

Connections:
GND: B1.-, C1.2, C2.2, C3.-, C4.-, C5.2, C6.2, C7.-, CON2.1, GND.1, GND.2, IC6.2 (GND), R1.1
unnamed: CON1.1, F1.1
unnamed: CX1.1, L2.3, SW2.MP
unnamed: CON1.2, CX1.2, L2.1
unnamed: F1.2, SW1.MP
unnamed: C4.+, C5.1, D2.C, IC6.1 (VI), L1.2
unnamed: CX2.1, L2.4, TR1.P2
unnamed: CX2.2, L2.2, TR1.P1
unnamed: B1.AC1, TR1.S2
unnamed: B1.AC2, TR1.S1
unnamed: LED1.K (C), R1.2
unnamed: D1.C, L1.1
unnamed: C6.1, C7.+, CON2.2, D2.A, IC6.3 (VO), J1.1, LED1.A
unnamed: 5V.1, 5V.2, C2.1, J1.2
VRECT: B1.+, C1.1, C3.+, D1.A

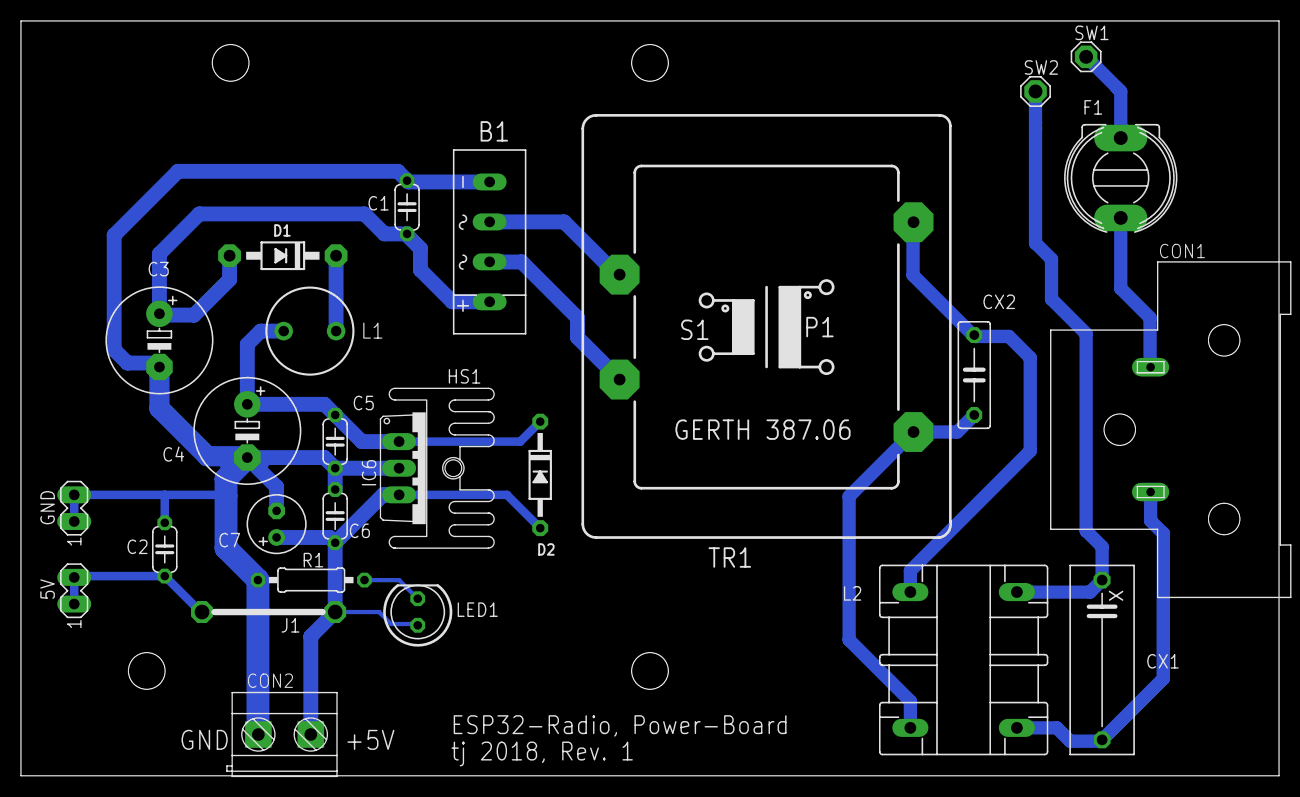
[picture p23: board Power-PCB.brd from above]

Board: 2 copper layers, 120.0 x 72.0 mm, 27 parts (0 on the bottom side), 15 nets.

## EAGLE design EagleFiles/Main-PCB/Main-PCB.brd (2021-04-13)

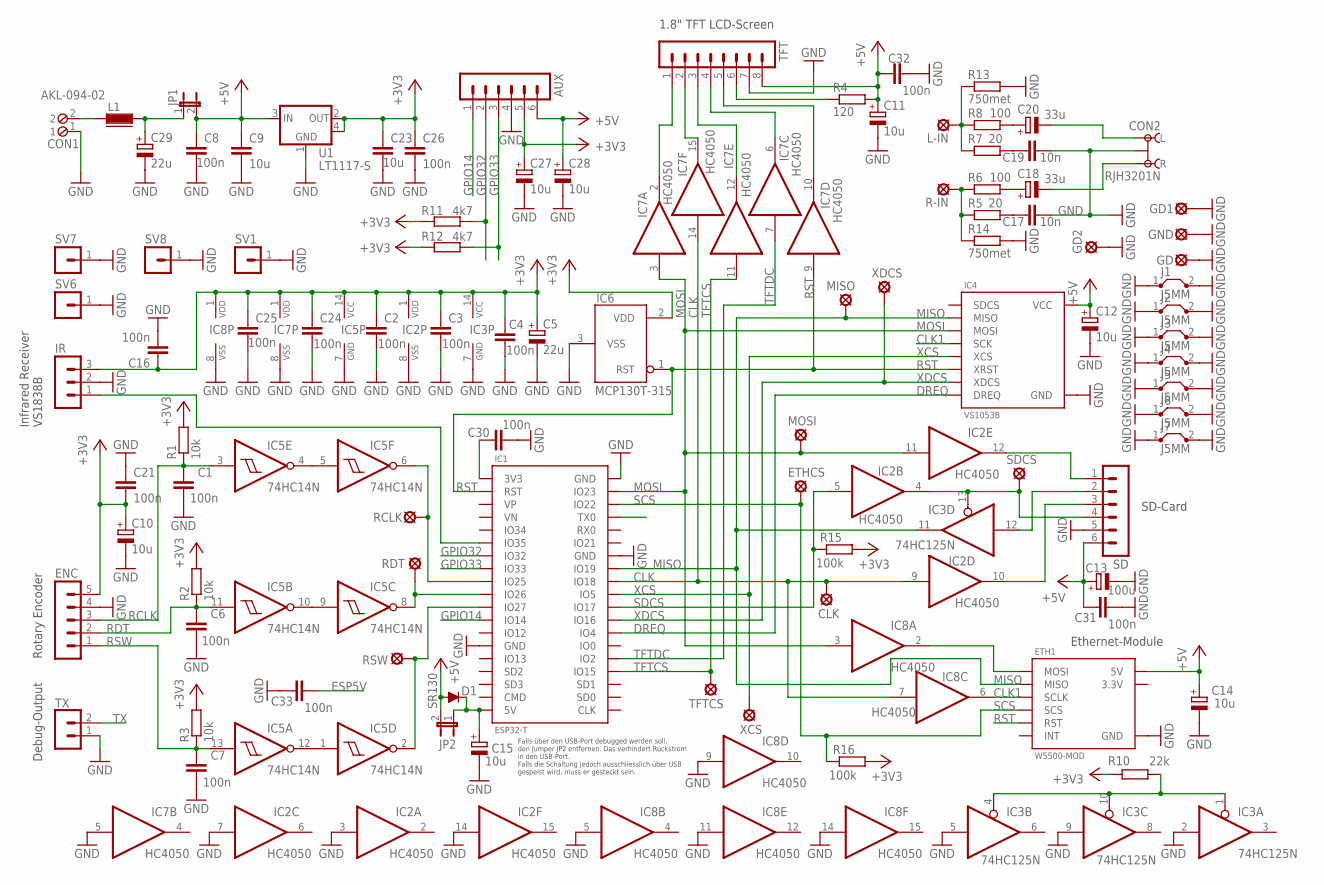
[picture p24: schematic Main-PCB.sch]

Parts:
AUX: MA06-1
C1, C6, C7: 100n; C050-024X044
C2, C3, C4, C8, C16, C21, C24, C25, C26, C30, C31, C32, C33: 100n; C1206
C5, C29: 22u; TT2D4
C9, C23: 10u; C1206
C10, C11, C14, C15, C27, C28: 10u; TT2D4
C12: 10u; TT2D4L
C13: 100u; E2,5-6
C17, C19: 10n; C1206
C18, C20: 33u; TT2D4
CLK: LSP11
CON1: AKL-094-02
CON2: RJH3201N; TECHNICS-RJH3201N
D1: SR130; D-7.5
ENC: MA05-1
ETH1: W5500-MOD
ETHCS: LSP11
GD, GD1: LSP11
GD2: SE13
GND: LSP11
IC1: ESP32-T
IC2, IC7, IC8: HC4050; DIL16
IC3: 74HC125N; DIL14
IC4: VS1053B
IC5: 74HC14N; DIL14
IC6: MCP130T-315; SOT-23
IR: MA03-1
J1, J2, J3, J4, J5, J6, J7: J5MM; 05
JP1, JP2: JP1E; JP1
L1: 07HCP
L-IN: LSP11
MISO: LSP11
MOSI: LSP11
R1, R2, R3: 10k; 0207/10
R4: 120; 0207/10
R5, R7: 20; R1206
R6, R8: 100; R1206
R10: 22k; R1206
R11, R12: 4k7; R1206
R13, R14: 750met; 0207/10
R15, R16: 100k; R1206
R-IN: LSP11
RCLK: LSP11
RDT: LSP11
RSW: LSP11
SD: MA06-1
SDCS: LSP11
SV1, SV6, SV7, SV8: MA01-1
TFT: MA08-1
TFTCS: LSP11
TX: MA02-1
U1: LT1117-S; SOT223
XCS: LSP11
XDCS: LSP11

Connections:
3.3V: ETH1.3.3V
+3V3: AUX.5, C2.1, C3.1, C4.1, C5.+, C10.+, C16.1, C21.2, C23.1, C24.1, C25.1, C26.1, C27.+, ENC.5, IC2.1 (VDD), IC3.14 (VCC), IC5.14 (VCC), IC6.2 (VDD), IC7.1 (VDD), IC8.1 (VDD), IR.3, R1.2, R2.2, R3.2, R10.1, R11.2, R12.2, R15.2, R16.2, U1.2 (OUT), U1.4 (TAB)
+5V: AUX.6, C8.1, C9.1, C11.+, C12.+, C13.+, C14.+, C28.+, C31.2, C32.2, D1.A, ETH1.5V, IC4.5V (VCC), JP1.2, JP2.2, R4.2, SD.6, TFT.8, U1.3 (IN)
CLK: CLK.MP, IC1.IO18, IC2.9 (I), IC7.14 (I), IC8.7 (I)
CLK1: ETH1.SCLK, IC4.SCK, IC8.6 (O)
DREQ: IC1.IO4, IC4.DREQ
ESP5V: C15.+, C33.1, D1.C, IC1.5V, JP2.1
ETHMOSI: ETH1.MOSI, IC8.2 (O)
GND: AUX.4, C1.2, C2.2, C3.2, C4.2, C5.-, C6.2, C7.2, C8.2, C9.2, C10.-, C11.-, C12.-, C13.-, C14.-, C15.-, C16.2, C17.2, C19.2, C21.1, C23.2, C24.2, C25.2, C26.2, C27.-, C28.-, C29.-, C30.2, C31.1, C32.1, C33.2, CON1.1, CON2.GND, ENC.4, ETH1.GND, GD.MP, GD1.MP, GD2.MP, GND.MP, IC1.GND, IC1.GND1 (GND), IC1.GND2 (GND), IC2.3 (I), IC2.7 (I), IC2.8 (VSS), IC2.14 (I), IC3.2 (I), IC3.5 (I), IC3.7 (GND), IC3.9 (I), IC4.GND, IC5.7 (GND), IC6.3 (VSS), IC7.5 (I), IC7.8 (VSS), IC8.5 (I), IC8.8 (VSS), IC8.9 (I), IC8.11 (I), IC8.14 (I), IR.2, J1.1, J1.2, J2.1, J2.2, J3.1, J3.2, J4.1, J4.2, J5.1, J5.2, J6.1, J6.2, J7.1, J7.2, R13.2, R14.2, SD.5, SV1.1, SV6.1, SV7.1, SV8.1, TFT.7, TX.1, U1.1 (GND)
GPIO14: AUX.1, IC1.IO14
GPIO32: AUX.2, IC1.IO32, R11.1
GPIO33: AUX.3, IC1.IO33, R12.1
IR: IC1.IO35, IR.1
MISO: ETH1.MISO, IC1.IO19, IC3.11 (O), IC4.MISO, MISO.MP
MOSI: IC1.IO23, IC2.11 (I), IC4.MOSI, IC7.3 (I), IC8.3 (I), MOSI.MP
unnamed: IC5.1 (I), IC5.12 (O)
unnamed: IC5.4 (O), IC5.5 (I)
unnamed: IC5.9 (I), IC5.10 (O)
unnamed: R4.1, TFT.6
unnamed: CON1.2, L1.1
unnamed: IC1.IO25, IC5.6 (O), RCLK.MP
unnamed: IC1.IO26, IC5.8 (O), RDT.MP
unnamed: C29.+, JP1.1, L1.2
unnamed: IC1.IO27, IC5.2 (O), RSW.MP
unnamed: C30.1, IC1.3V3
unnamed: R5.1, R6.1, R14.1, R-IN.MP
unnamed: C17.1, R5.2
unnamed: C18.+, R6.2
unnamed: C18.-, CON2.R
unnamed: L-IN.MP, R7.1, R8.1, R13.1
unnamed: C19.1, R7.2
unnamed: C20.+, R8.2
unnamed: C20.-, CON2.L
unnamed: IC3.1 (OE), IC3.4 (OE), IC3.10 (OE), R10.2
RCLK: C1.1, ENC.3, IC5.3 (I), R1.1
RDT: C6.1, ENC.2, IC5.11 (I), R2.1
RST: ETH1.RST, IC1.RST, IC4.XRST, IC6.1 (RST), IC7.9 (I)
RSW: C7.1, ENC.1, IC5.13 (I), R3.1
SCS: ETH1.SCS, ETHCS.MP, IC1.IO22, R16.1
SDCLK: IC2.10 (O), SD.3
SDCS: IC1.IO17, IC2.5 (I), R15.1
SDCS1: IC2.4 (O), IC3.13 (OE), SD.4, SDCS.MP
SDMISO: IC3.12 (I), SD.2
SDMOSI: IC2.12 (O), SD.1
TFTCLK: IC7.15 (O), TFT.2
TFTCS: IC1.IO15, IC7.11 (I), TFTCS.MP
TFTCS1: IC7.12 (O), TFT.3
TFTDC: IC1.IO2, IC7.7 (I)
TFTDC1: IC7.6 (O), TFT.4
TFTMOSI: IC7.2 (O), TFT.1
TFTRST: IC7.10 (O), TFT.5
TX: IC1.TX0, TX.2
XCS: IC1.IO5, IC4.XCS, XCS.MP
XDCS: IC1.IO16, IC4.XDCS, XDCS.MP

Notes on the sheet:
1.8" TFT LCD-Screen
SD-Card
Ethernet-Module
Rotary Encoder
Infrared Receiver VS1838B
Falls über den USB-Port debugged werden soll, den Jumper JP2 entfernen. Das verhindert Rückstrom in den USB-Port. Falls die Schaltung jedoch ausschliesslich über USB gespeist wird, muss er gesteckt sein.
Debug-Output

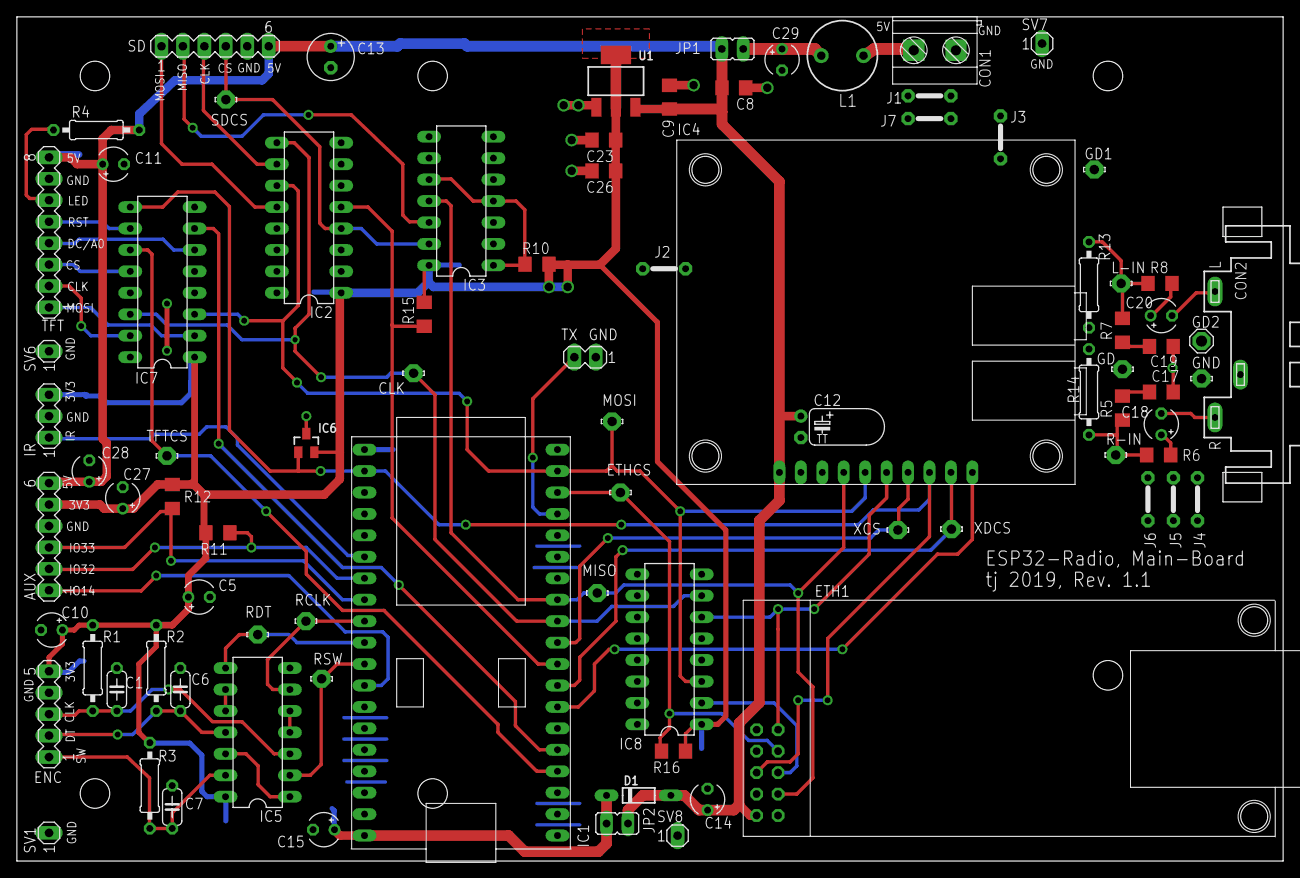
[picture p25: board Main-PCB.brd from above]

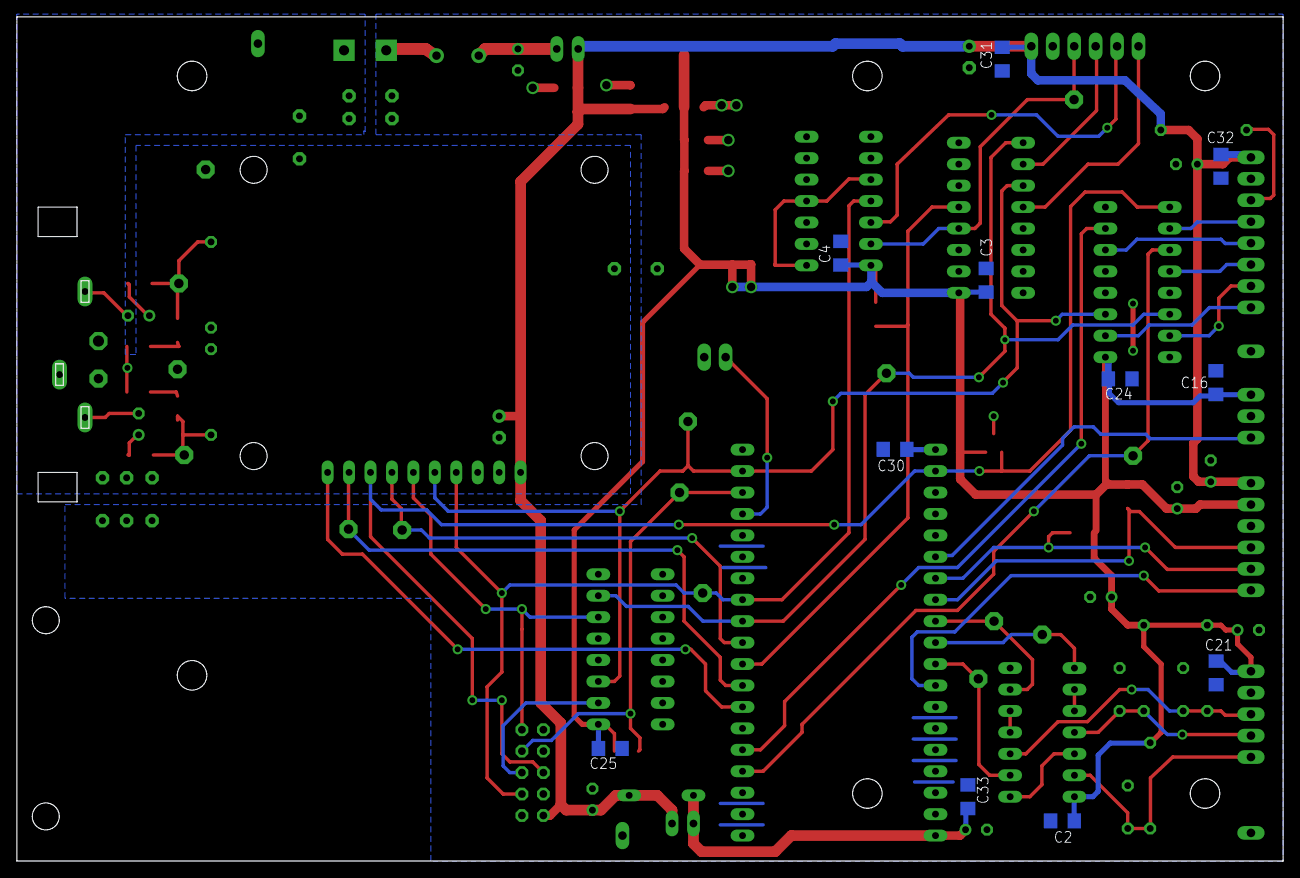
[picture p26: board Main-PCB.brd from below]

Board: 2 copper layers, 150.0 x 100.0 mm, 97 parts (11 on the bottom side), 53 nets.

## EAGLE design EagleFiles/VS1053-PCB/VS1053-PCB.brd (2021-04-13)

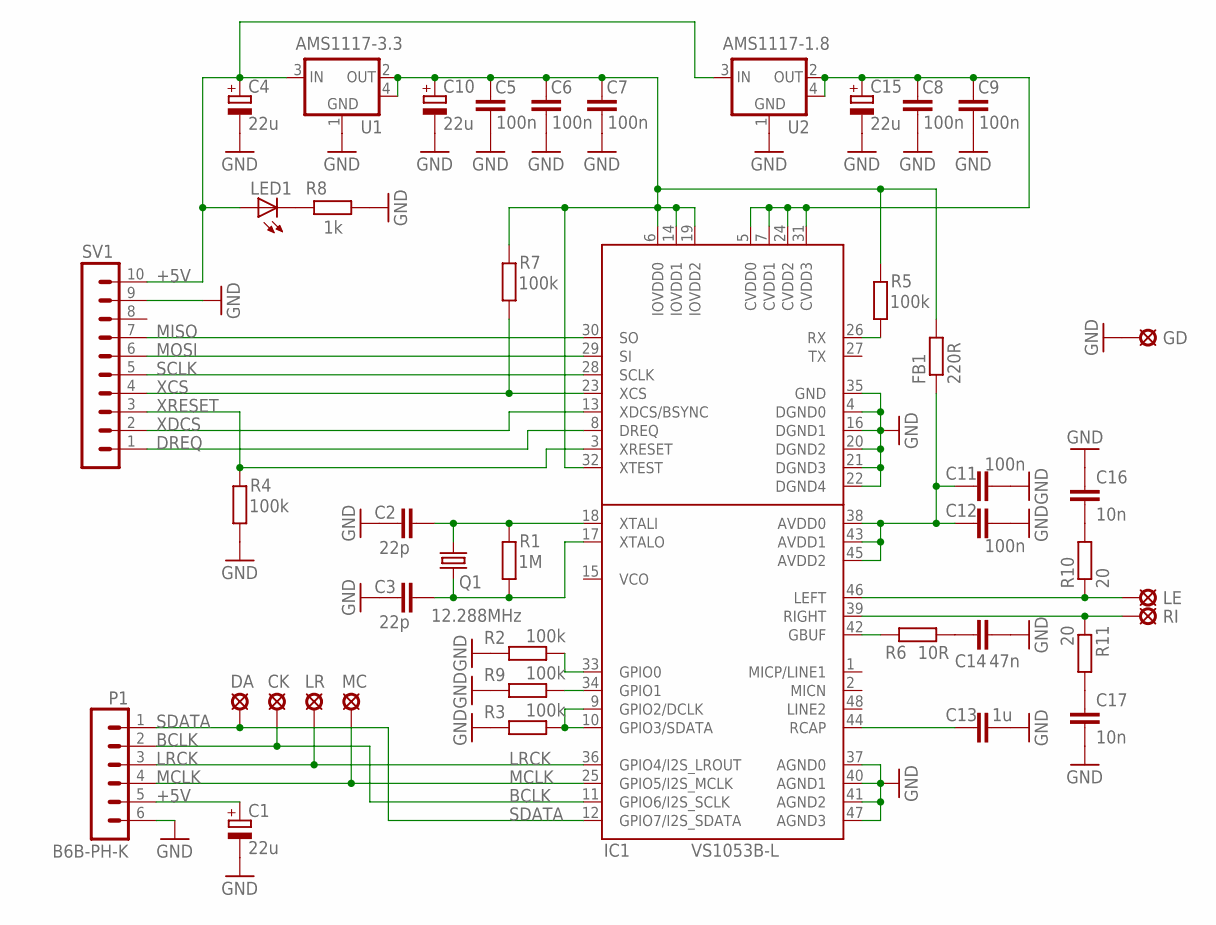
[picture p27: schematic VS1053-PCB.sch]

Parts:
C1, C4, C10, C15: 22u; CT3528
C2, C3: 22p; C0805
C5, C6, C7, C8, C9, C11, C12: 100n; C0805
C13: 1u; C0805
C14: 47n; C0805
C16, C17: 10n; C0603
CK: SOLPAD-MINI
DA: SOLPAD-MINI
FB1: 220R; R0805
GD: LSP10-ROUND
IC1: VS1053B-L; QFP50P900X900X160-48N
LE: LSP10-ROUND
LED1: LEDCHIPLED_0805; CHIPLED_0805
LR: SOLPAD-MINI
MC: SOLPAD-MINI
P1: B6B-PH-K
Q1: 12.288MHz; HC49/S
R1: 1M; R0805
R2, R3, R4, R5, R7, R9: 100k; R0805
R6: 10R; R0805
R8: 1k; R0805
R10, R11: 20; R0603
RI: LSP10-ROUND
SV1: MA10-1-THIN
U1: AMS1117-3.3; SOT223
U2: AMS1117-1.8; SOT223

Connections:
3.3VA: C11.1, C12.1, FB1.1, IC1.38 (AVDD0), IC1.43 (AVDD1), IC1.45 (AVDD2)
+1.8V: C8.1, C9.1, C15.+, IC1.5 (CVDD0), IC1.7 (CVDD1), IC1.24 (CVDD2), IC1.31 (CVDD3), U2.2 (OUT), U2.4 (TAB)
+3.3V: C5.1, C6.1, C7.1, C10.+, FB1.2, IC1.6 (IOVDD0), IC1.14 (IOVDD1), IC1.19 (IOVDD2), IC1.32 (XTEST), R5.2, R7.2, U1.2 (OUT), U1.4 (TAB)
+5V: C1.+, C4.+, LED1.A, P1.5, SV1.10, U1.3 (IN), U2.3 (IN)
BCLK: CK.1, IC1.11 (GPIO6/I2S_SCLK), P1.2
DREQ: IC1.8 (DREQ), SV1.1
GND: C1.-, C2.1, C3.1, C4.-, C5.2, C6.2, C7.2, C8.2, C9.2, C10.-, C11.2, C12.2, C13.2, C14.2, C15.-, C16.1, C17.2, GD.MP, IC1.4 (DGND0), IC1.16 (DGND1), IC1.20 (DGND2), IC1.21 (DGND3), IC1.22 (DGND4), IC1.35 (GND), IC1.37 (AGND0), IC1.40 (AGND1), IC1.41 (AGND2), IC1.47 (AGND3), P1.6, R2.2, R3.2, R4.1, R8.2, R9.2, SV1.9, U1.1 (GND), U2.1 (GND)
LRCK: IC1.36 (GPIO4/I2S_LROUT), LR.1, P1.3
MCLK: IC1.25 (GPIO5/I2S_MCLK), MC.1, P1.4
MISO: IC1.30 (SO), SV1.7
MOSI: IC1.29 (SI), SV1.6
unnamed: C2.2, IC1.18 (XTALI), Q1.2, R1.2
unnamed: C3.2, IC1.17 (XTALO), Q1.1, R1.1
unnamed: IC1.9 (GPIO2/DCLK), IC1.10 (GPIO3/SDATA), R3.1
unnamed: IC1.33 (GPIO0), R2.1
unnamed: IC1.42 (GBUF), R6.1
unnamed: C13.1, IC1.44 (RCAP)
unnamed: C14.1, R6.2
unnamed: IC1.39 (RIGHT), R11.1, RI.MP
unnamed: IC1.26 (RX), R5.1
unnamed: IC1.46 (LEFT), LE.MP, R10.1
unnamed: IC1.34 (GPIO1), R9.1
unnamed: LED1.C, R8.1
unnamed: C16.2, R10.2
unnamed: C17.1, R11.2
SCLK: IC1.28 (SCLK), SV1.5
SDATA: DA.1, IC1.12 (GPIO7/I2S_SDATA), P1.1
XCS: IC1.23 (XCS), R7.1, SV1.4
XDCS: IC1.13 (XDCS/BSYNC), SV1.2
XRESET: IC1.3 (XRESET), R4.2, SV1.3

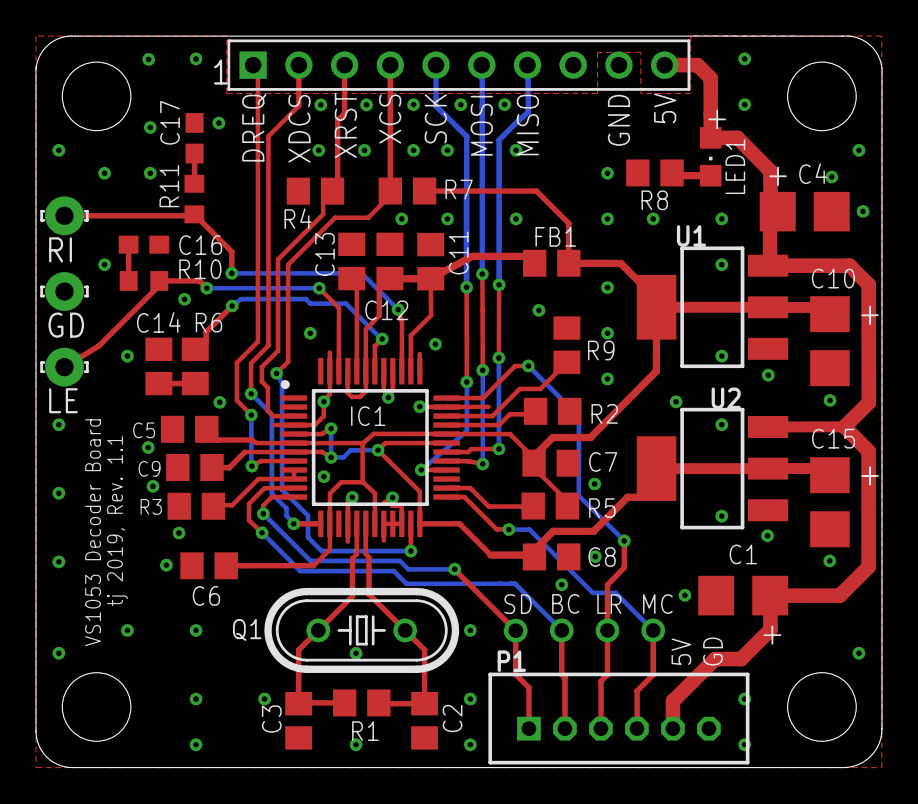
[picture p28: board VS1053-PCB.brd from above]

Board: 2 copper layers, 47.0 x 40.6 mm, 43 parts (0 on the bottom side), 30 nets.

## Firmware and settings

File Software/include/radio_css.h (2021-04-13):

// radio.css file in raw data format for PROGMEM
//
const char radio_css[] PROGMEM = R"=====(
body {
   background-color: lightblue;
   font-family: Arial, Helvetica, sans-serif;
}

h1 {
   color: navy;
   margin-left: 20px;
   font-size: 150%
}

ul {
   list-style-type: none;
   margin: 0;
   margin-left: -10px;
   overflow: hidden;
   background-color: #2C3E50;
   position:fixed;
   top:0;
   width:100%;
   z-index:100;
}

li .pull-left {
   float: left;
}

li .pull-right {
   float: right;
}

li a {
   display: block;
   color: white;
   text-align: center;
   padding: 14px 16px;
   text-decoration: none;
}

li a:hover, a.active {
   background-color: #111;
}

.button {
   width: 90px;
   height: 30px;
   background-color: #128F76;
   border: none;
   color: white;
   text-align: center;
   text-decoration: none;
   display: inline-block;
   font-size: 16px;
   margin: 4px 2px;
   cursor: pointer;
   border-radius: 10px;
}

.buttonr {background-color: #D62C1A;}

.select {
   width: 160px;
   height: 32px;
   padding: 5px;
   background: white;
   font-size: 16px;
   line-height: 1;
   border: 1;
   border-radius: 5px;
   -webkit-border-radius: 5px;
   -moz-border-radius: 5px;
   -webkit-appearance: none;
   border: 1px solid black;
   border-radius: 10px;
}

.selectw {width: 410px;}

input[type="text"] {
   margin: 0;
   height: 28px;
   background: white;
   font-size: 16px;
   appearance: none;
   box-shadow: none;
   border-radius: 5px;
   -webkit-border-radius: 5px;
   -moz-border-radius: 5px;
   -webkit-appearance: none;
   border: 1px solid black;
   border-radius: 10px;
}

input[type="text"]:focus {
  outline: none;
}

input[type=submit] {
  width: 200px;
  height: 40px;
  background-color: #128F76;
  border: none;
  color: white;
  text-align: center;
  text-decoration: none;
  display: inline-block;
  font-size: 16px;
  margin: 4px 2px;
  cursor: pointer;
  border-radius: 5px;
}

textarea {
  width: 80;
  height: 25;
  border: 1px solid black;
  border-radius: 10px;
  padding: 5px;
  font-family: Courier, "Lucida Console", monospace;
  background-color: white;
  resize: none;
})=====" ;

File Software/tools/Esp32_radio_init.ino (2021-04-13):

//********************************************************************************************
// Initialize the preferences op ESP32-radio.  They can be edited later by the webinterface. *
//********************************************************************************************
// 27-04-2017, ES: First set-up, derived from preferences example sketch.                    *
// 11-02-2019, ES: names of I/O pins changed.                                                *
//********************************************************************************************

#include <Preferences.h>

// Note: Namespace name is limited to 15 chars.  Same name must be used in ESP32-radio.
#define NAME "ESP32Radio"
// Adjust size of buffer to the longest expected string for nvsgetstr
#define NVSBUFSIZE 150

Preferences preferences ;         // Instance of Preferences


//******************************************************************************************
//                              S E T U P                                                  *
//******************************************************************************************
void setup()
{
  String       str ;
  
  Serial.begin ( 115200 ) ;
  Serial.println() ;
  preferences.begin ( NAME, false ) ;                 // Open for read/write
  preferences.clear() ;                               // Remove all preferences under opened namespace
  // Store the preferences for ESP32-radio
  preferences.putString ( "gpio_00",  "uppreset = 1" ) ;
  preferences.putString ( "gpio_12",  "upvolume = 2" ) ;
  preferences.putString ( "gpio_13",  "downvolume = 2" ) ;

  preferences.putString ( "mqttbroker",   "none" ) ;
  preferences.putString ( "mqttport",     "1883" ) ;
  preferences.putString ( "mqttuser",     "none" ) ;
  preferences.putString ( "mqttpasswd",   "none" ) ;
  preferences.putString ( "mqttprefix",   "none" ) ;
  //
  preferences.putString ( "wifi_00",     "NETGEAR-11/xxxxxx" ) ;
  preferences.putString ( "wifi_01",     "SSID2/YYYYYY" ) ;
  //
  preferences.putString ( "volume",      "72" ) ;
  preferences.putString ( "toneha",      "0" ) ;
  preferences.putString ( "tonehf",      "0" ) ;
  preferences.putString ( "tonela",      "0" ) ;
  preferences.putString ( "tonelf",      "0" ) ;
  //
  preferences.putString ( "preset",      "6" ) ;
  preferences.putString ( "preset_00",   "109.206.96.34:8100                       #  0 - NAXI LOVE RADIO, Belgrade, Serbia" ) ;
  preferences.putString ( "preset_01",   "airspectrum.cdnstream1.com:8114/1648_128 #  1 - Easy Hits Florida 128k" ) ;
  preferences.putString ( "preset_02",   "us2.internet-radio.com:8050              #  2 - CLASSIC ROCK MIA WWW.SHERADIO.COM" ) ;
  preferences.putString ( "preset_03",   "airspectrum.cdnstream1.com:8000/1261_192 #  3 - Magic Oldies Florida" ) ;
  preferences.putString ( "preset_04",   "airspectrum.cdnstream1.com:8008/1604_128 #  4 - Magic 60s Florida 60s Classic Rock" ) ;
  preferences.putString ( "preset_05",   "us1.internet-radio.com:8105              #  5 - Classic Rock Florida - SHE Radio" ) ;
  preferences.putString ( "preset_06",   "icecast.omroep.nl:80/radio1-bb-mp3       #  6 - Radio 1, NL" ) ;
  preferences.putString ( "preset_07",   "205.164.62.15:10032                      #  7 - 1.FM - GAIA, 64k" ) ;
  preferences.putString ( "preset_08",   "skonto.ls.lv:8002/mp3                    #  8 - Skonto 128k" ) ;
  preferences.putString ( "preset_09",   "94.23.66.155:8106                        #  9 - *ILR CHILL and GROOVE" ) ;
  preferences.putString ( "preset_10",   "ihr/IHR_IEDM                             # 10 - iHeartRadio IHR_IEDM" ) ;
  preferences.putString ( "preset_11",   "ihr/IHR_TRAN                             # 11 - iHeartRadio IHR_TRAN" ) ;
  //
  preferences.putString ( "clk_server",  "pool.ntp.org" ) ;        // Setting for Time Of Day clock on TFT
  preferences.putString ( "clk_offset",  "1" ) ;
  preferences.putString ( "clk_dst",     "1" ) ;
  //
  preferences.putString ( "pin_ir",      "35                                     # GPIO Pin number for IR receiver VS1838B" ) ;
  preferences.putString ( "ir_40BF",     "upvolume = 2" ) ;
  preferences.putString ( "ir_C03F",     "downvolume = 2" ) ;
  //
  preferences.putString ( "pin_vs_cs",   "5                                      # GPIO Pin number for VS1053 CS" ) ;
  preferences.putString ( "pin_vs_dcs",  "16                                     # GPIO Pin number for VS1053 DCS" ) ;
  preferences.putString ( "pin_vs_dreq", "4                                      # GPIO Pin number for VS1053 DREQ" ) ;
  //
  preferences.putString ( "pin_enc_clk", "25                                     # GPIO Pin number for rotary encoder CLK" ) ;
  preferences.putString ( "pin_enc_dt",  "26                                     # GPIO Pin number for rotary encoder DT" ) ;
  preferences.putString ( "pin_enc_sw",  "27                                     # GPIO Pin number for rotary encoder SW" ) ;
  //
  preferences.putString ( "pin_tft_cs",  "15                                     # GPIO Pin number for TFT CS" ) ;
  preferences.putString ( "pin_tft_dc",  "2                                      # GPIO Pin number for TFT DC" ) ;
  //
  preferences.putString ( "pin_sd_cs",   "21                                     # GPIO Pin number for SD card CS" ) ;

  preferences.end() ;
  delay ( 1000 ) ;
}


//******************************************************************************************
//                              L O O P                                                    *
//******************************************************************************************
void loop()
{
  Serial.println ( "ESP32_radio_init completed..." ) ;
  delay ( 10000 ) ;
}

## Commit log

2021-04-13 First release
    [Extender-PCB.brd, Extender-PCB.sch, Main-PCB.brd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]
2022-07-14 modification for espressif32 framework >= V4.2.0
    1) required modification for Arduino espressif32 framework >= V4.2.0
    (successful PlatformIO builds for V4.2.0 & V5.0.0)
    2) minor improvements
2023-10-10 Create Main Board.jpg
2024-01-26 Update I2S to OPT Board Schematic.jpg
